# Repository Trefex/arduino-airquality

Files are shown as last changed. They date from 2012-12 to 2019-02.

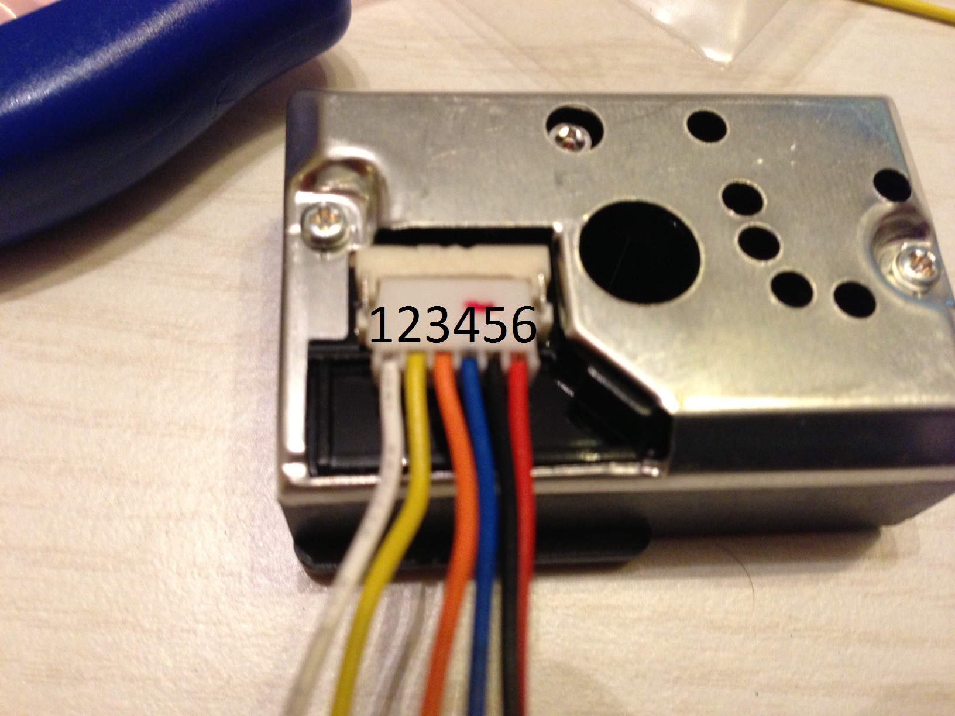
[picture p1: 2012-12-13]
Module_Dust-Sensor/assembly/_BlogImages/Arduino_Dust2.JPG

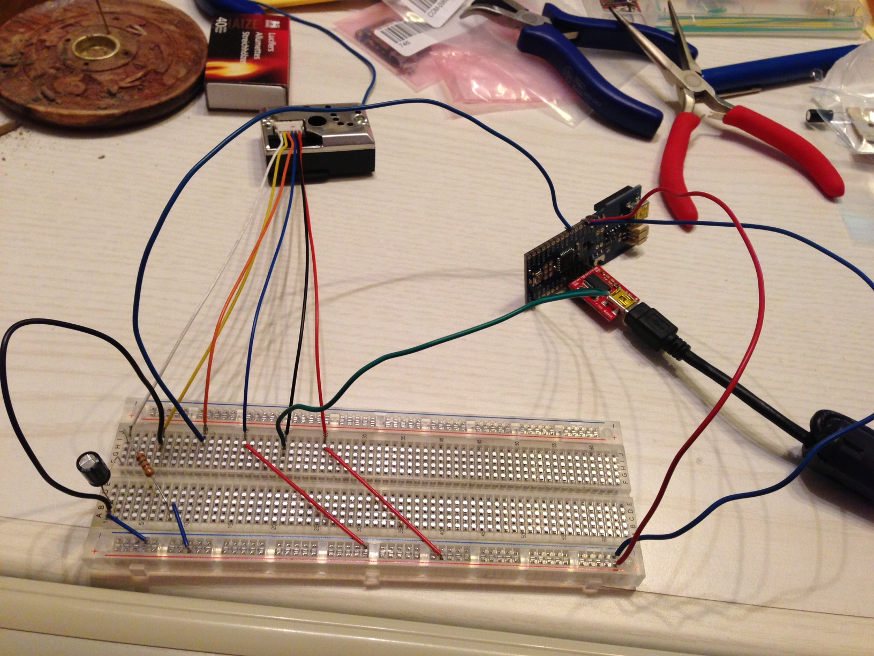
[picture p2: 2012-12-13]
Module_Dust-Sensor/assembly/_BlogImages/Arduino_Dust1.JPG

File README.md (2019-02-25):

arduino-airquality
==================
      
In this project, we are building a mobile Arduino Fio based platform to measure air quality.

We currently have multiple components working correctly with the Arduino Fio:

- [x] GPS sensor - Adafruit Ultimate GPS Breakout v3 and the OpenLog
- [x] Dust sensor - Sharp Optical Dust Sensor
- [x] Humidity and temperature sensor - SHT10 by sensiron/DFRobot
- [x] Carbon monoxide sensor - Parallax CO sensor
- [x] Barometric pressure - BMP085 Barometric Pressure/Temperature/Altitude Sensor

We are working on combining them all into a nice light package.

Still to do:
- [x] Create circuit board sketch and etch it
- [x] Solder everything on board
- [x] Build enclosure

Next version improvements:

1. Use smaller arduino board (Nano?) potentially one with GPS builtin.

2. Decide if we want a 5V board.

3. Use 7.4V LI-ion flat and rechargeable battery pack.

4. Use only one voltage regulator if we stay with 3.3V.

5. Move voltage splitter to monitor voltage to between battery and voltage regulator.

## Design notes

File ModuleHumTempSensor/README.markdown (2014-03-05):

SHT1x Temperature / Humidity Sensor Library for Arduino
=======================================================
Heavily modified by Cyrille Medard de Chardon from the original creator's version:

Copyright 2009 Jonathan Oxer jon@oxer.com.au / http://www.practicalarduino.com  
Copyright 2008 Maurice Ribble ribblem@yahoo.com / http://www.glacialwanderer.com

It now provides a simple interface to the SHT10 sensor made to function with the Arduino Fio (3.3V)

Installation
------------
Put this directory in your sketchbook and open the ino file.

Usage
-----
The library is instantiated as an object with methods provided to read
relative humidity and temperature. Include it in your sketch and then
create an object, specifying the pins to use for communication with the
sensor:

    #include "SHT1x.h"
    #define dataPin 10
    #define clockPin 11
    SHT1x sht10(dataPin, clockPin);

You can then call methods on that object within your program. In this
example we created an object called "sht10", but it could have been
called whatever you like.

### readTemperatureC() ###

Returns a float within the valid range of the sensor of -40 to +123.8C.
A value of -273 is returned in the event of a communication error with
the sensor.

Example:

    float tempC = sht10.readTemperatureC();

### retrieveTemperatureC() ###

Returns a float of the temperature in celcius that was measured during the humidity measurement. This prevents needing two calls to the temperature sensor. Call the humidty function readHumidity() then retrieveTemperatureC().

### readHumidity() ###

Returns a float within the valid range of the sensor of 0 to 100%.
A negative value is returned in the event of a communication error with
the sensor.

Example:

    float humidity = sht1x.readHumidity();

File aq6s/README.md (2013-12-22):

arduino-airquality - CO Sensor
==================

2013-Dec-22
	- You need to add the StandardCpp folder to your Arduino Library, or the Sketch will not compile

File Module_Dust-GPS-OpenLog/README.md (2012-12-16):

arduino-airquality - Combine Dust Sensor - GPS - OpenLog
==================

In this project, we are building a combination module of the Sharp Dust Sensor, the Adafruit Ultimate GPS Breakout v3 and the OpenLog using the Arduino Fio.

For a detailled documentation including a parts list, check out the following blog post
http://arduinodev.woofex.net/2012/12/16/sharp-dust-sensor-with-adafruit-gps-v3

# Assembly

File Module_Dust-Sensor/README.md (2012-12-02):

arduino-airquality - Dust Sensor
==================

In the Dust Sensor Module, we are building a standalone Dust Sensor using the Arduino Fio.

For a detailled documentation including a parts list, check out the following blog post
http://arduinodev.woofex.net/2012/12/01/standalone-sharp-dust-sensor/

# Assembly

Dust_SensorArduino

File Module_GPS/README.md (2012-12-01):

arduino-airquality - GPS
==================

In the GPS Module, we are building a standalone GPS device using the Arduino Fio.
This will be used as a module in the AirQuality project.

Stay tuned for updates.

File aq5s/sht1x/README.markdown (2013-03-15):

SHT1x Temperature / Humidity Sensor Library for Arduino
=======================================================
Heavily modified from the original creator's version:
Copyright 2009 Jonathan Oxer jon@oxer.com.au / http://www.practicalarduino.com  
Copyright 2008 Maurice Ribble ribblem@yahoo.com / http://www.glacialwanderer.com

Provides a simple interface to the SHT10 sensor. Made to function with the Arduino Fio (3.3V)

Installation
------------
Download the directory "SHT1x" and move it into the "libraries"
directory inside your sketchbook directory, then restart the Arduino
IDE. You will then see it listed under File->Examples->SHT1x.

Usage
-----
The library is instantiated as an object with methods provided to read
relative humidity and temperature. Include it in your sketch and then
create an object, specifying the pins to use for communication with the
sensor:

    #include <SHT1x.h>
    #define dataPin 10
    #define clockPin 11
    SHT1x sht10(dataPin, clockPin);

You can then call methods on that object within your program. In this
example we created an object called "sht10", but it could have been
called whatever you like. A complete example program is included with
the library and can be accessed from the File->Examples->SHT1x menu.

### readTemperatureC() ###

Returns a float within the valid range of the sensor of -40 to +123.8C.
A value of -273 is returned in the event of a communication error with
the sensor.

Example:

    float tempC = sht10.readTemperatureC();

### retrieveTemperatureC() ###

Returns a float of the temperature in celcius that was measured during the humidity measurement. This prevents needing two calls to the temperature sensor. Call the humidyt function readHumidity() then retrieveTemperatureC().

### readHumidity() ###

Returns a float within the valid range of the sensor of 0 to 100%.
A negative value is returned in the event of a communication error with
the sensor.

Example:

    float humidity = sht1x.readHumidity();

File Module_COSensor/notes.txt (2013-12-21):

Note regarding Gas Sensor Module (GSM)
- only interested in TP1 which varies from 0V - 5V
- not interested in other TP (TP2/4 GRND, TP3 Alarm trip level)
- don't need to calibrate trip level screw on left, other than set it very high so it actually is a coherent visual warning..
- adding a 1k resistor between TP1 and Fio
- soldered wire to TP1

CO sensor:
When heating should pull about 165 mA, 60mA when 'off'
Needs a 5V signal to heat switch (HSW) to turn it on
Needs a 1.4V signal to HSW to let the sensor 'cool'

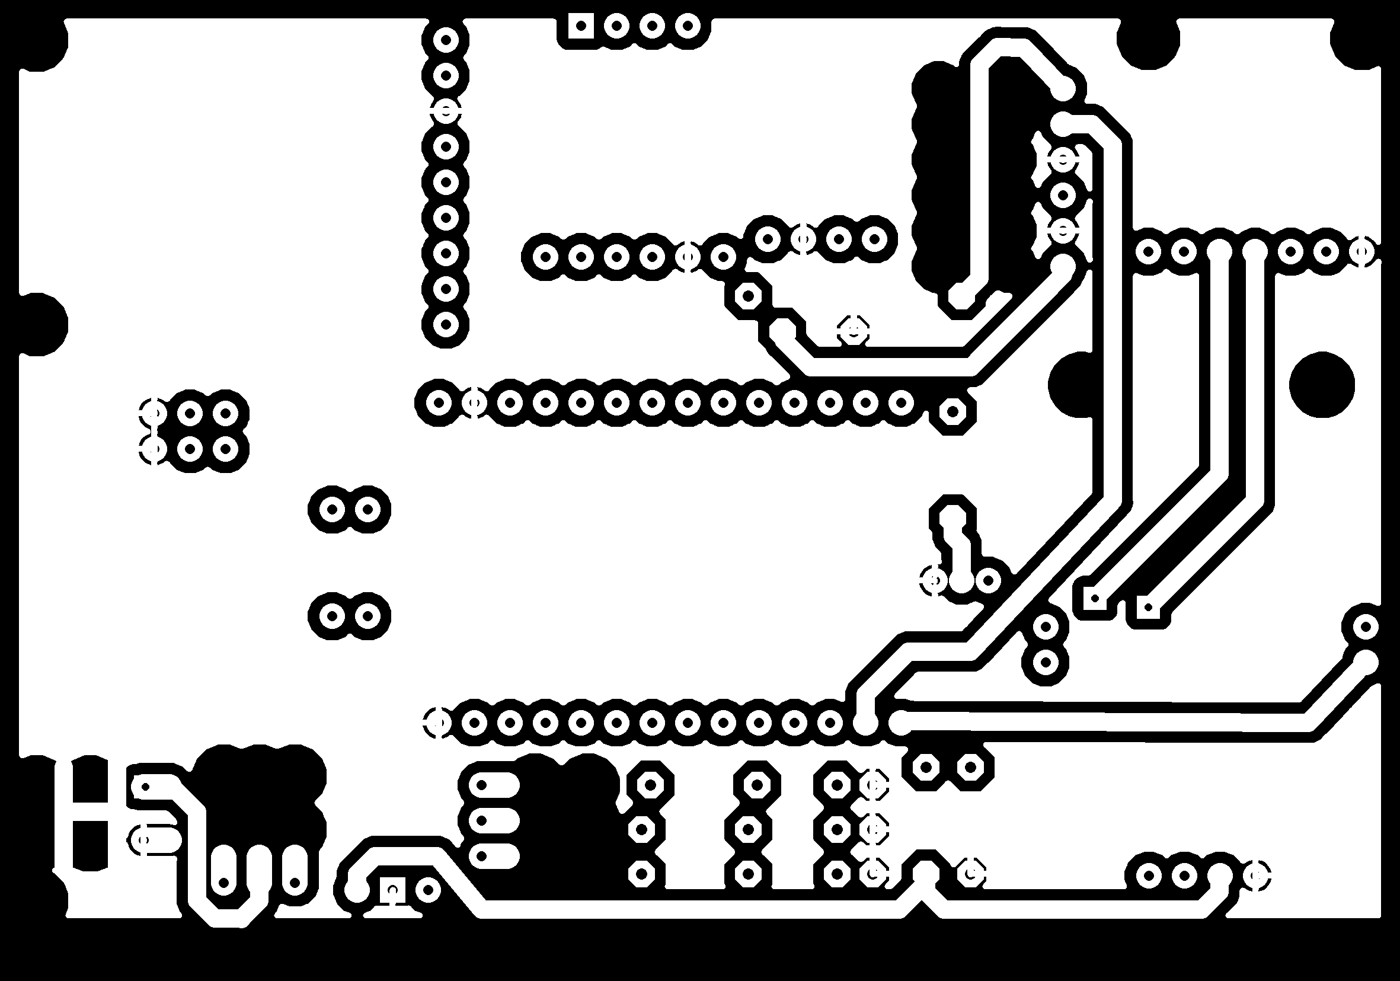
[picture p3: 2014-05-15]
schematics/Eagle/aq6s/pcb_design/top.png

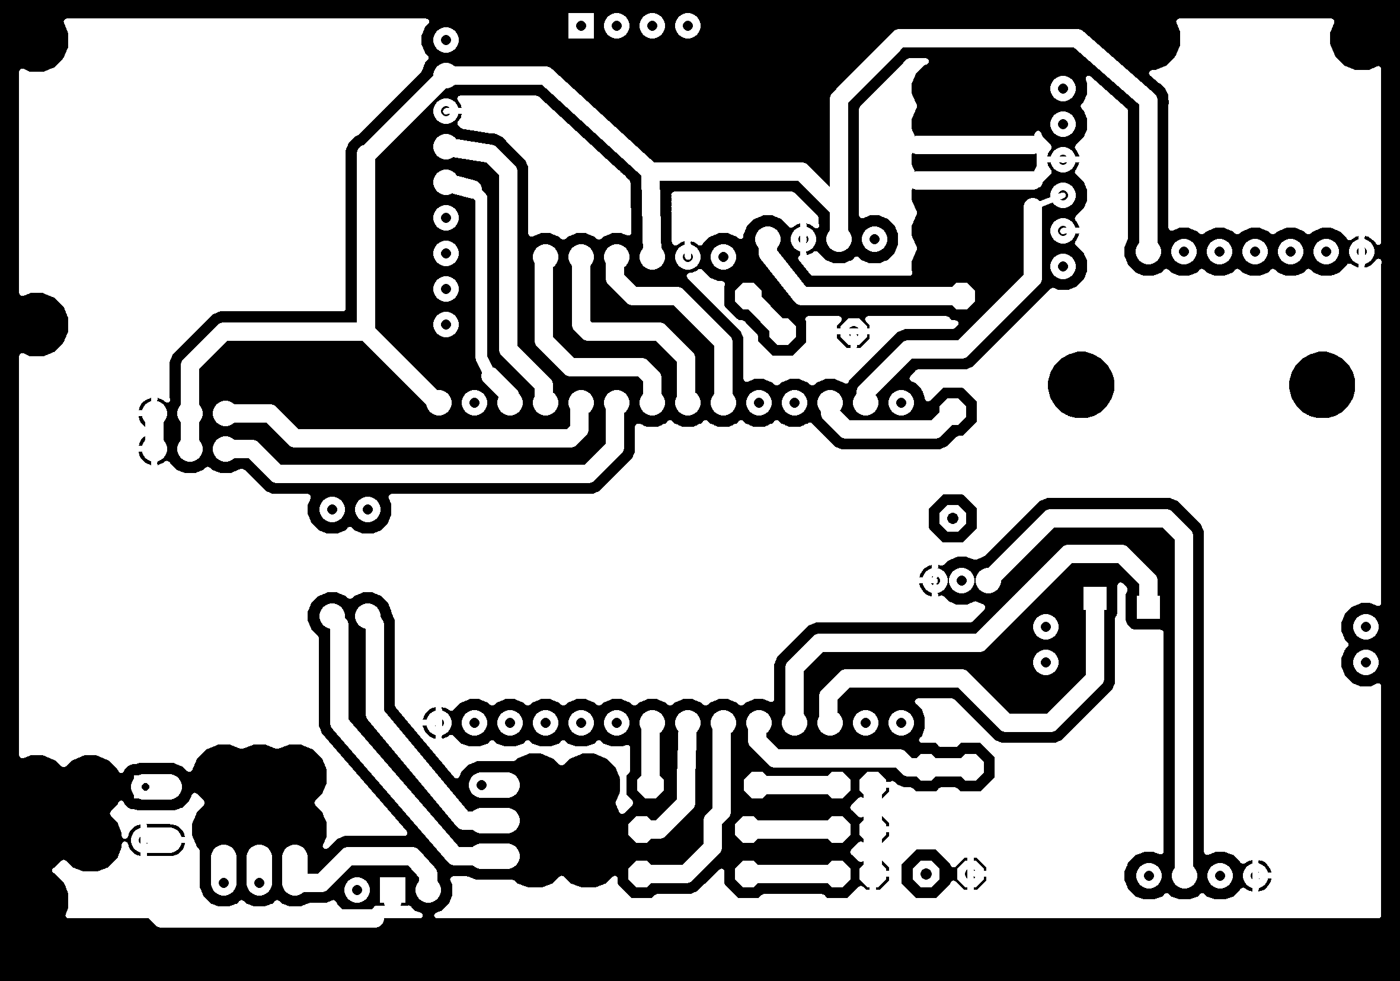
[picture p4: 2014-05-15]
schematics/Eagle/aq6s/pcb_design/bottom.png

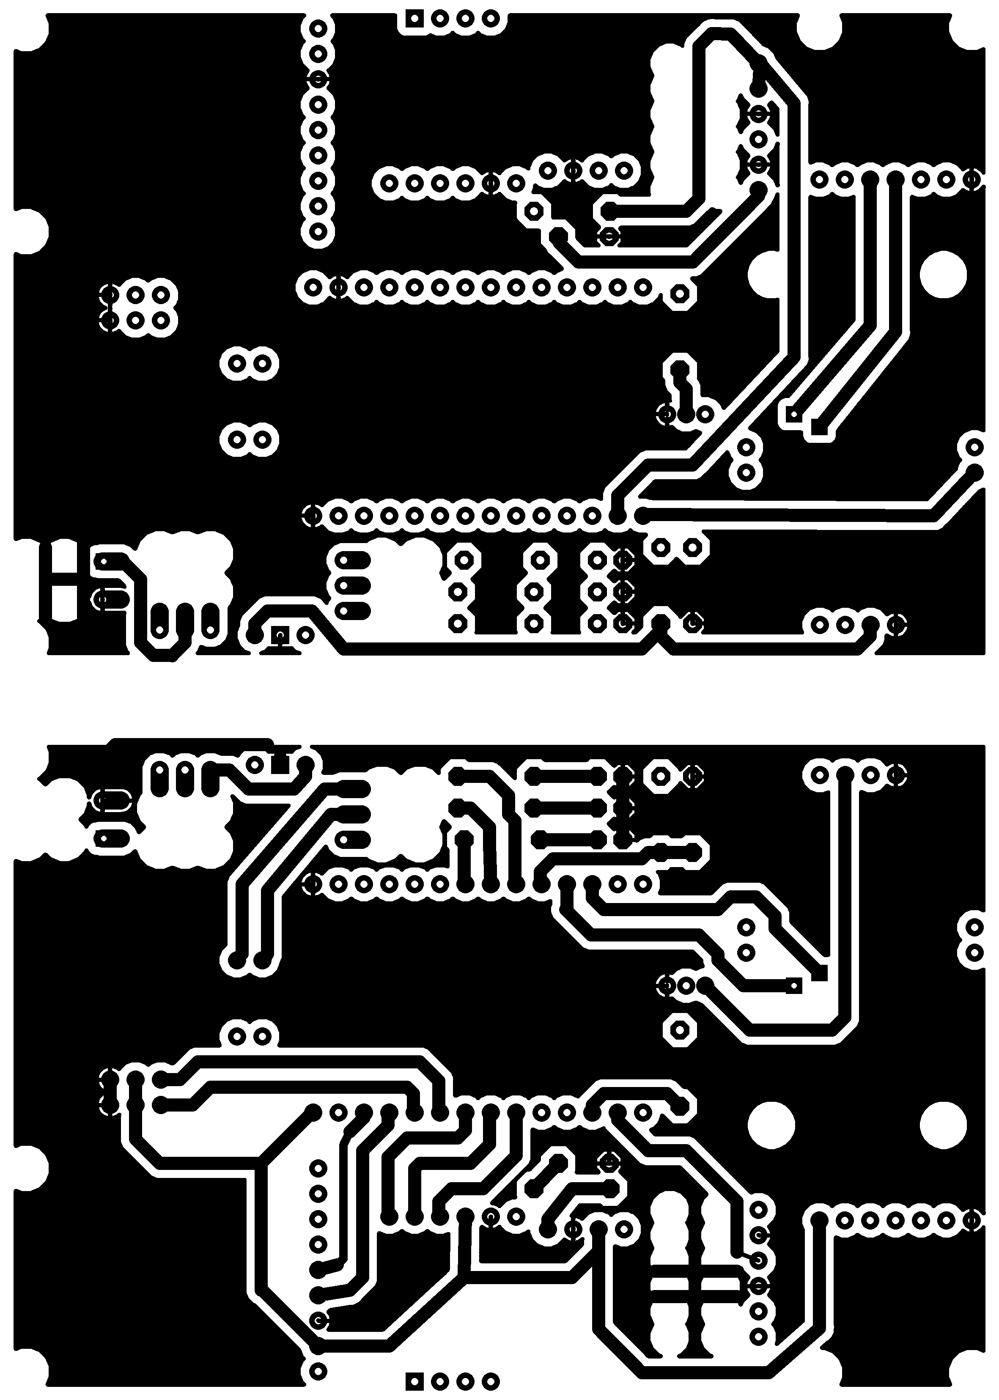
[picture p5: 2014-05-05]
schematics/Eagle/aq6s/pcb_design/both.png

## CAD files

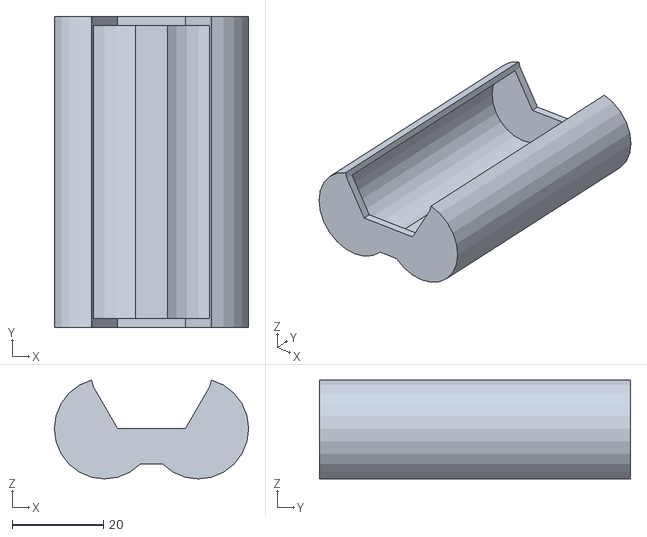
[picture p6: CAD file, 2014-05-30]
battery_holder/battery_holder.stl
42.5 x 68.0 x 21.6

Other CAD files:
battery_holder/battery_holder.skp
battery_holder/battery_holder_stretch.skp
battery_holder/battery_holder_stretch~.skp
battery_holder/battery_holder~.skp

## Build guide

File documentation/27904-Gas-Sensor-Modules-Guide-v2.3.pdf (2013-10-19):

Web Site: www.parallax.com Forums: forums.parallax.com Sales: sales@parallax.com
Technical: support@parallax.com

Office: (916) 624-8333
Fax: (916) 624-8003
Sales: (888) 512-1024
Tech Support: (888) 997-8267

Copyright © Parallax Inc. Gas Sensor Modules (#27930, #27931, #27932, #27904) v2.3 11/27/2012 Page 1 of 5

# Parallax Gas Sensor Modules

CH4 (Methane) Gas Sensor Module (#27930)
CO (Carbon Monoxide) Gas Sensor Module (#27931)
LPG (Propane) Gas Sensor Module (#27932)
C2H5OH (Alcohol) Gas Sensor Module (#27904)

These Gas Sensor Modules are designed to allow a microcontroller to determine when a preset gas level has been reached or exceeded. The type of gas detected depends on which module you are using. 27930 detects Methane (CH4), 27931 detects Carbon Monoxide (CO), 27932 detects Propane (LPG) and 27904 detects Alcohol (C2H5OH). Interfacing with these sensors is done through a 4-pin SIP header and requires two I/O pins from the host microcontroller. The sensor modules are intended to provide a means of comparing gas sources and being able to set an alarm limit when the source becomes excessive.

Parallax does not provide gas calibration data on these modules and such data as well as the alarm settings are the responsibility of the user to define. For information on calibration please see page 3.

### Features

- Easy SIP header interface
- Compatible with most microcontrollers
- Low-power standby mode

### Key Specifications

- Power requirements: 5 VDC @ ~165 mA (heater on) / ~60 mA (heater off)
- Interface: 1 TTL compatible input (HSW); 1 TTL compatible output (ALR)
- Operating temperature:
14 to 122 °F (-10 to +50°C)
- Dimensions: 1.50 x 1.0 x 1.0 in
(38.1 x 25.4 x 25.4 mm)

### Application Ideas

- Gas level over-limit alarm
- Stand-alone/background sensing device
- Environmental monitoring equipment

### Packing List

- Gas Sensor
- Gas Sensor PCB Assembly

### Other Items Required

- Tiny flat-head screwdriver
- A source of gas for calibration

### Product Change Notice

This documentation is written for the Gas Sensor Modules listed at the top of this documentation that include a PCB labeled “Gas Sensor Board Rev A (#27983).” If you have a product where the PCB is labeled “Gas Sensor Module” with the gas type and one of the following part numbers on the PCB (27930, 27931, 27932, 27904), please see the Product Change Notice Details on page 5.

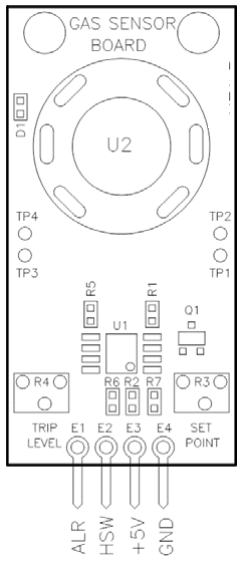
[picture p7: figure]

Copyright © Parallax Inc. Gas Sensor Modules (#27930, #27931, #27932, #27904)v2.3 11/27/2012 Page 2 of 5

### Precautions

Be aware that the gasses detected by these gas sensors can be deadly in high concentrations. Automotive exhaust and charcoal cooking grill exhausts emit carbon monoxide (CO). Propane Gas (LPG) can leak from propane grills and furnaces and Methane (CH4) can be found in animal farming areas. Always be careful to perform gas tests in well-ventilated areas.

THESE GAS SENSOR MODULES ARE NOT DESIGNED FOR OR APPROVED FOR ANY APPLICATION INVOLVING HEALTH OR HUMAN SAFETY. THESE GAS SENSOR MODULES ARE FOR EXPERIMENTAL PURPOSES ONLY. PARALLAX, INC. ABSOLVES ITSELF OF ALL LIABILITY AND RESPONSIBILITY ASSOCIATED WITH THE CUSTOMER'S USE OF THESE GAS SENSOR MODULES AND IS NOT RESPONSIBLE FOR ANY BODILY INJURY, DEATH OR PROPERTY DAMAGE AS A RESULT OF USING THESE GAS SENSOR MODULES.

### Connecting and Testing

The gas sensor canister plugs into the socket on the front of the module. The gas sensors are essentially resistive devices and are not polarized, so there is no need to be concerned about plugging it in “backwards.” It will work in either orientation.

The 4-pin SIP header on the Gas Sensor Module makes it easy to connect to a breadboard or SIP socket. The four connections are defined in the table below. Connection to a 5V microcontroller, such as the BASIC Stamp® module, would be pretty straight forward and require two I/O pins; one input for detecting the alarm signal and the other an output for controlling the internal heater.

For a 3.3 V microcontroller such as the PropellerTM chip, a 3.9 kΩ–10 kΩ resistor would be required from the ALR output to the Propeller chip input pin.

### Pin Definitions and Ratings – Gas Sensor Board

Pin | Name | Function | Level
E1 | ALR | Alarm output to host microcontroller | 0V / 5V
E2 | HSW | Heat switch input from microcontroller, active high | 0V / High*
E3 | +5V | +5 VDC power | 5V
E4 | GND | Ground, connects to common ground | 0V
TP1 | Test Point 1+ | Buffered output of sensors (voltage divider) | 0V – 5V
TP2 | Test Point 2- | Ground, connects to common ground | 0V
TP3 | Test Point 3+ | Trip Level voltage set by potentiometer (R4) | 0V – 5V
TP4 | Test Point 4- | Ground, connects to common ground | 0V
* The HSW can be activated from 3-5 VDC and has an internal 150 kΩ pull-down resistor.
NOTE: Sensor may rattle if shaken – this is normal.

Copyright © Parallax Inc. Gas Sensor Modules (#27930, #27931, #27932, #27904)v2.3 11/27/2012 Page 3 of 5

### Theory of Operation

These gas sensor modules use gas sensors from Hanwei Electronics. When their internal heating elements are activated, they respond to their specific gas by reducing their resistance in proportion to the amount of that gas present in the air exposed to the internal element. On the gas sensor modules this is part of a voltage divider formed by the internal element of each gas sensor and potentiometer R3 (Set Point). The output of this voltage divider is fed into the non-inverting inputs of the two op-amps on the LT1013 dual op-amp IC. Op-amp A is configured as a buffer with unity gain and is used to provide a non-loaded test point for the signal voltage at TP1 (+) and TP2 (-). The signal voltage is also being fed into op-amp B which is configured as a comparator that gets its reference voltage at the inverting input from potentiometer R4 (Trip Level) and is also available at TP3 (+) and TP4 (-).

The output of op-amp B goes out to the ALR pin through a 1 kΩ resistor providing a TTL-compatible signal to a microcontroller. This output also connects to a red LED on the gas sensor modules. The zero gas span adjustment is set via potentiometer R3. As mentioned above R3 allows you to change the span/range of the voltage divider formed by the gas sensor and R3 which is the bottom leg of the divider, electrically speaking. Adjusting R3 to lower values will make the gas sensor less sensitive but more stable. Avoid setting R3 below 200 ohms as at this point you will be close to shorting the output to ground. Setting R3 to higher values will make the gas sensor more responsive, but without a minimum load it will become unstable after a certain point. The trip level adjustment is set via potentiometer R4. This is just a simple voltage divider that lets you set the voltage from 0V to 5V. This voltage is compared to the voltage coming from the gas sensor/R3 divider. When the voltage from the gas sensor is higher than the voltage set by potentiometer R4 the red LED will light and the ALR output will be high (5 V). The section below describes how to configure these gas sensor modules to detect gas with minimal calibration.

One more important item to consider when setting R3 during calibration is the load resistance recommended in the datasheet for each gas sensor. Potentiometer R3 should be set as close as possible to the load resistance recommended for the gas sensor you’re using.

### Calibration

The procedure for setting these potentiometers is explained below. Please note that turning the potentiometer clockwise decreases voltage, while turning the potentiometer counter-clockwise increases it. This can be compared to a water valve.

- For the CO sensor, please read the CO Sensor Specifics on page 4 before attempting calibration.
- Place the Gas Sensor Module in a clean air environment and supply power to the module. The heater should be active during this time. Allow at least 10 minutes before making adjustments.
- Adjust potentiometer R4 until the voltage across TP3 (+) and TP4 (-) reads ~ 0.80 V.
- Adjust potentiometer R3 until the voltage across TP1 (+) and TP2 (-) reads ~ 0.80 V.
- At this point adjusting R3 up/down should make the LED toggle on/off. Adjust R3 so the LED just goes off.
- Apply your gas source to the gas sensor. The LED should light up.
- Remove the gas source and allow the sensor to settle. The LED should go back out.
- If the LED does not go out within 60 seconds, adjust R3 until the LED goes out and repeat the two previous steps.

The gas sensor module’s ALR pin should only be checked when the heater is on and the readings have stabilized. Note that temperature and humidity are factors that could affect the sensor, making calibration difficult. If this should happen try adjusting the voltages used in the calibration up or down as necessary to find a more stable range.

Copyright © Parallax Inc. Gas Sensor Modules (#27930, #27931, #27932, #27904)v2.3 11/27/2012 Page 4 of 5

### CO Sensor Specifics

The CO gas sensor must cycle through alternating voltages on its heater when active. This is unlike the CH4, LPG, and C2H5OH gas sensors where the heater is on or off. To sense CO gas using the CO gas sensor the heater must be driven at 5 V (full power) for the purge phase and 1.4 V (low power) for the sense phase. The full-power (purge) phase runs for 60 seconds and the low-power (sense) phase runs for 90 seconds. These phases cycle continuously as long as the sensor is active. The ALR output is checked during the sense phase only. Checking it during the purge phase or when the heater is not active could result in false positives.

In order to power the CO gas sensor from 5V and still obtain 1.4 V for the sense phase it is necessary to pulse-width modulate (PWM) the HSW pin. Example source code is provided for the BASIC Stamp 2 module (see your gas sensor’s product page; search by stock code at http://www.parallax.com) and Propeller chip (see the Propeller Object Exchange, http://obex.parallax.com).

### Sources of Gas for Calibration / Testing

The use of a standard butane hair curler is an easy, safe source to use for a very low carbon monoxide (CO) gas concentration (less than 500 ppm) and can be used during calibration and testing of the CO Gas Sensor Module.

An unlit propane torch can be used as a source for calibration and testing of the LPG Gas Sensor Module. These are readily available from any hardware store and most department stores. Be careful not to leave the valve open very long. Simply cracking the valve just a little can trigger the gas sensor.

We have not found an easy reliable source of methane for calibration and testing of the CH4 Gas Sensor Module, however the CH4 gas sensor is responsive to propane as well so that could be used for testing.

Breathing gently through a small plastic tube (a drinking straw will work) can be used for calibrating the C2H5OH Gas Sensor Module. The tube will help get the gas to the sensor and should condense most of the water vapor in your breath that may interfere with the sensor. Breathe out very, very slowly! Air movement across the sensor can cool the heater, causing erroneous readings.

### Resources and Downloads

You may download the module schematic as well as the manufacturer datasheet for the sensor from each gas sensor module’s product page. Go to http://www.parallax.com, and search by the specific product number.

For gas calibration information you can also visit the following PDF on this website: http://www.gotgas.com/pdf/GasSnsrCalibratn.pdf

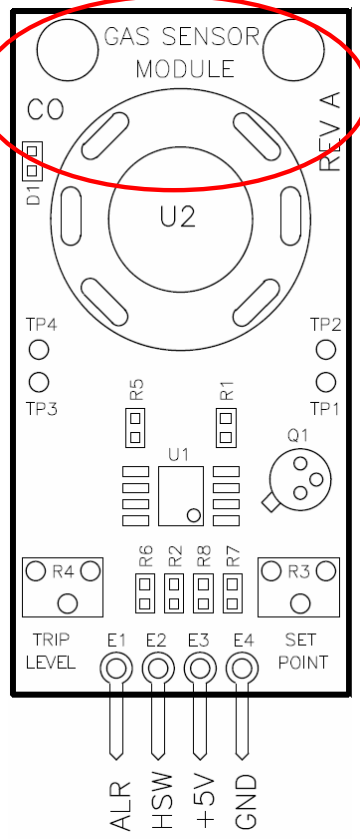
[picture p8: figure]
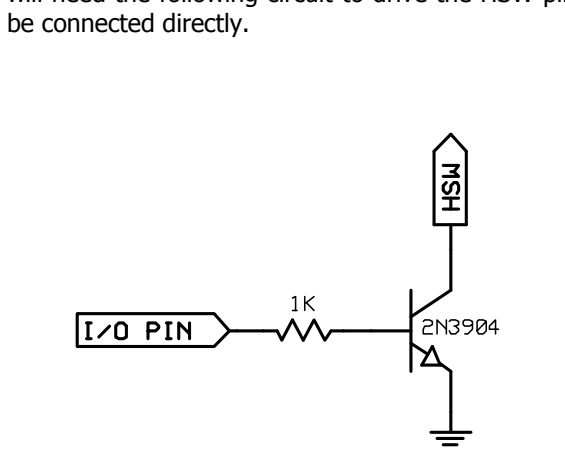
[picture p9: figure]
be connected directly.

Copyright © Parallax Inc. Gas Sensor Modules (#27930, #27931, #27932, #27904)v2.3 11/27/2012 Page 5 of 5

### Product Change Notice Details

This section applies to covers product numbers 27930, 27931, 27932 and 27904 where the PCB is labeled as “Gas Sensor Module” with the type of gas indicated below the left mounting hole (see drawing, right).

The HSW input is active-low and is pulled to 5 V via an internal 10 kΩ resistor.

Code examples (especially those using the CO sensor) will require changes to drive the line low at the desired duty cycle during on times and release the pin during off times. You can release an I/O pin by making it an input.

If you have a 3.3 V microcontroller such as the Propeller chip you will need the following circuit to drive the HSW pin as it should not

### Pin Definitions and Ratings – Gas Sensor Modules

Pin | Name | Function | Level
E1 | ALR | Alarm output to host microcontroller | 0V / 5V
E2 | HSW | Heat switch input from microcontroller, active low | 0V / Floating*
E3 | +5V | +5 VDC power | 5V
E4 | GND | Ground, connects to common ground | 0V
TP1 | Test Point 1+ | Buffered output of sensors (voltage divider) | 0V – 5V
TP2 | Test Point 2- | Ground, connects to common ground | 0V
TP3 | Test Point 3+ | Trip Level voltage set by potentiometer (R4) | 0V – 5V
TP4 | Test Point 4- | Ground, connects to common ground | 0V
* The HSW line is internally pulled up to 5 V via a 10 kΩ resistor.
NOTE: Sensor may rattle if shaken – this is normal.

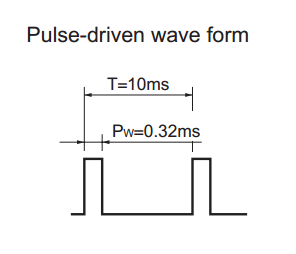
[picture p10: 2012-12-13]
Module_Dust-Sensor/assembly/_BlogImages/Sharp_PulseWidth.PNG

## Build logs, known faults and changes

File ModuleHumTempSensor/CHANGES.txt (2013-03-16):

2013-03-16
 * Renamed and moved files, changed #include path, now works out of the box with arduino
2013-02-22
 * Completely changed the library to handle Arduion Fio's 3.3V.
 * Minor fixes/cleaning
 * Removed fahrenheit functions for temperature
 * Removed direct temperature requests, can only be requested after a humidity request (this prevents too many sequential temperature requests which will heat the sensor... (humidity request do a temperature request, we hold this for later retrieval)

2011-09-20
 * Conditionally include Arduino.h for compatibility with Arduino 1.0

2010-07-23
 * Added SHT7x to list of supported sensors.
 * Fixed temperature offset in humidity calculation.

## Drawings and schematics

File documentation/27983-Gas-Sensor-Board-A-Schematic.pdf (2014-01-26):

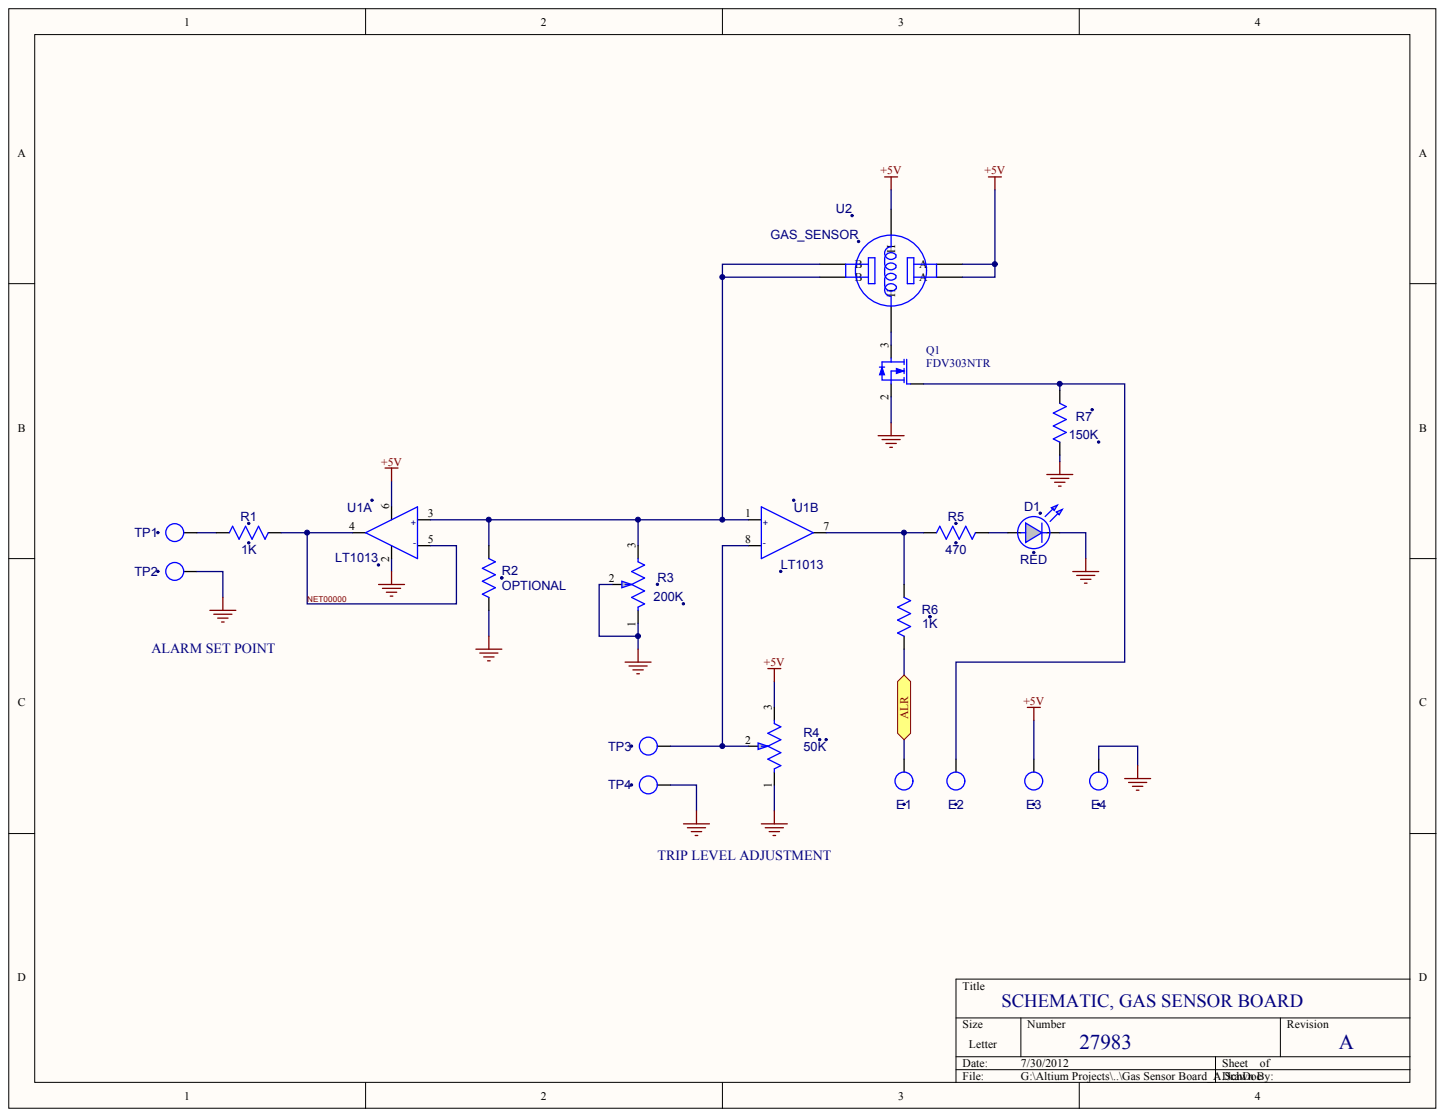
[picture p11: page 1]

SCHEMATIC, GAS SENSOR BOARD

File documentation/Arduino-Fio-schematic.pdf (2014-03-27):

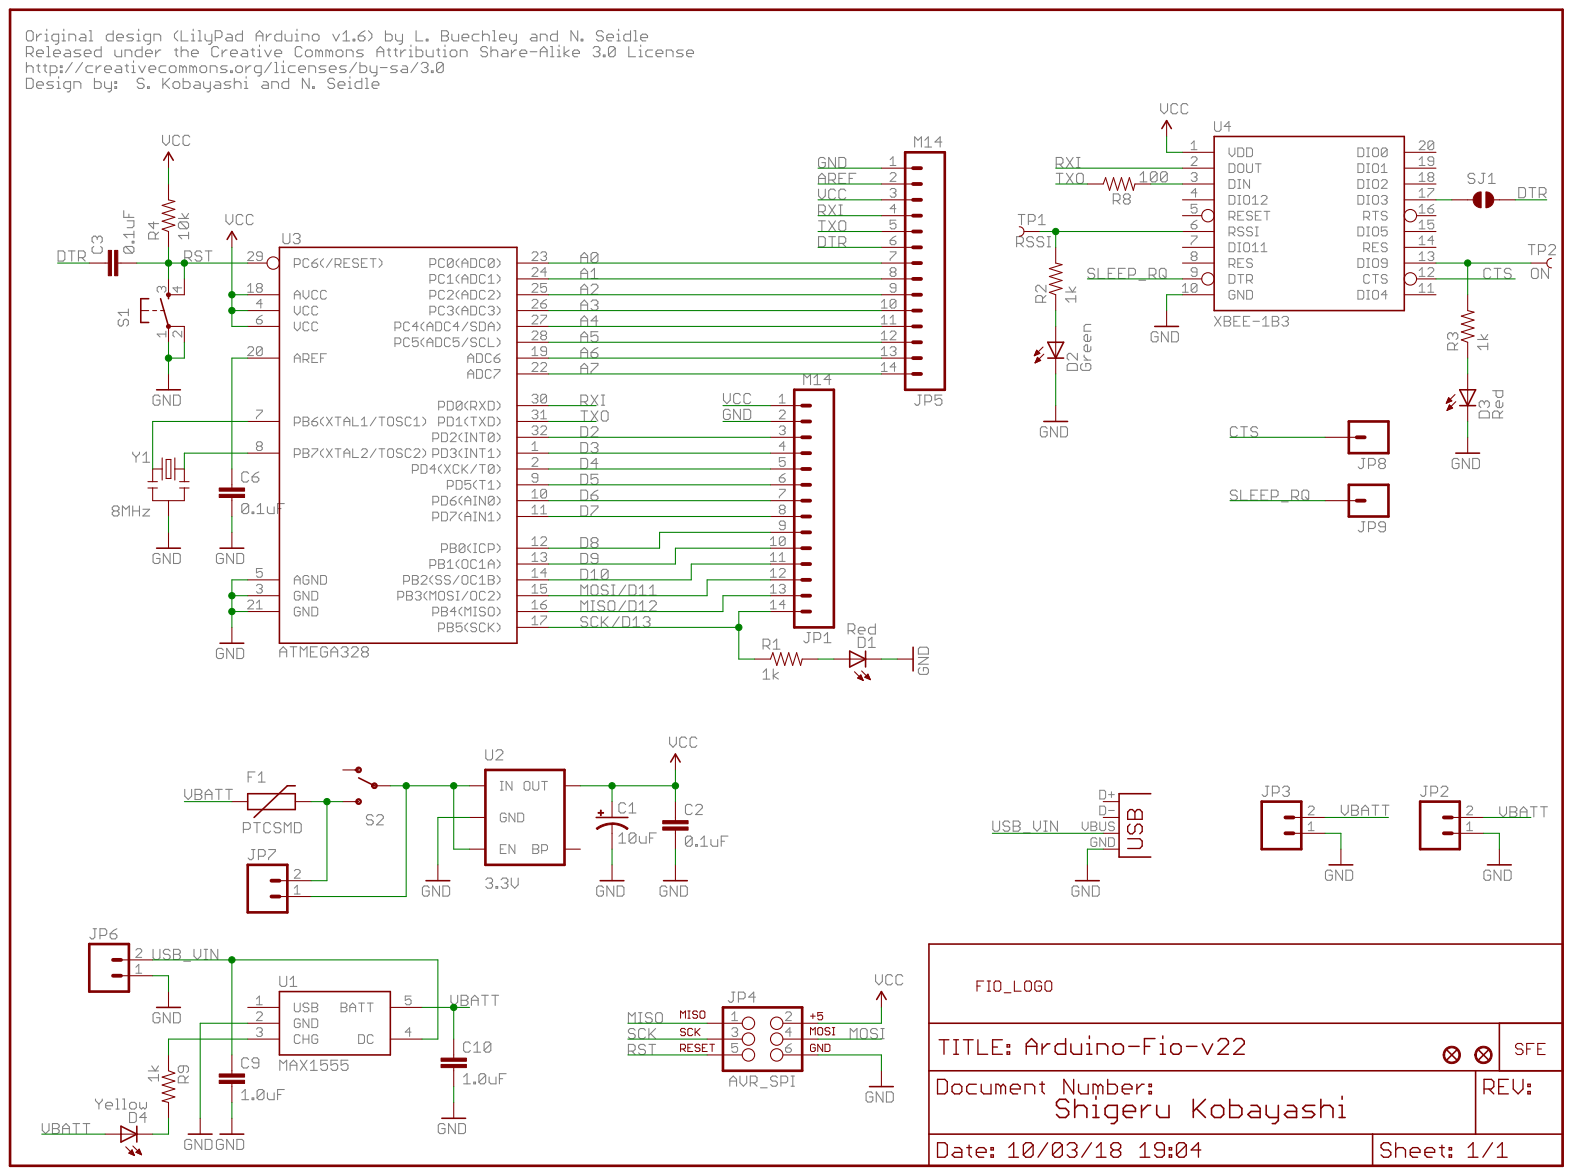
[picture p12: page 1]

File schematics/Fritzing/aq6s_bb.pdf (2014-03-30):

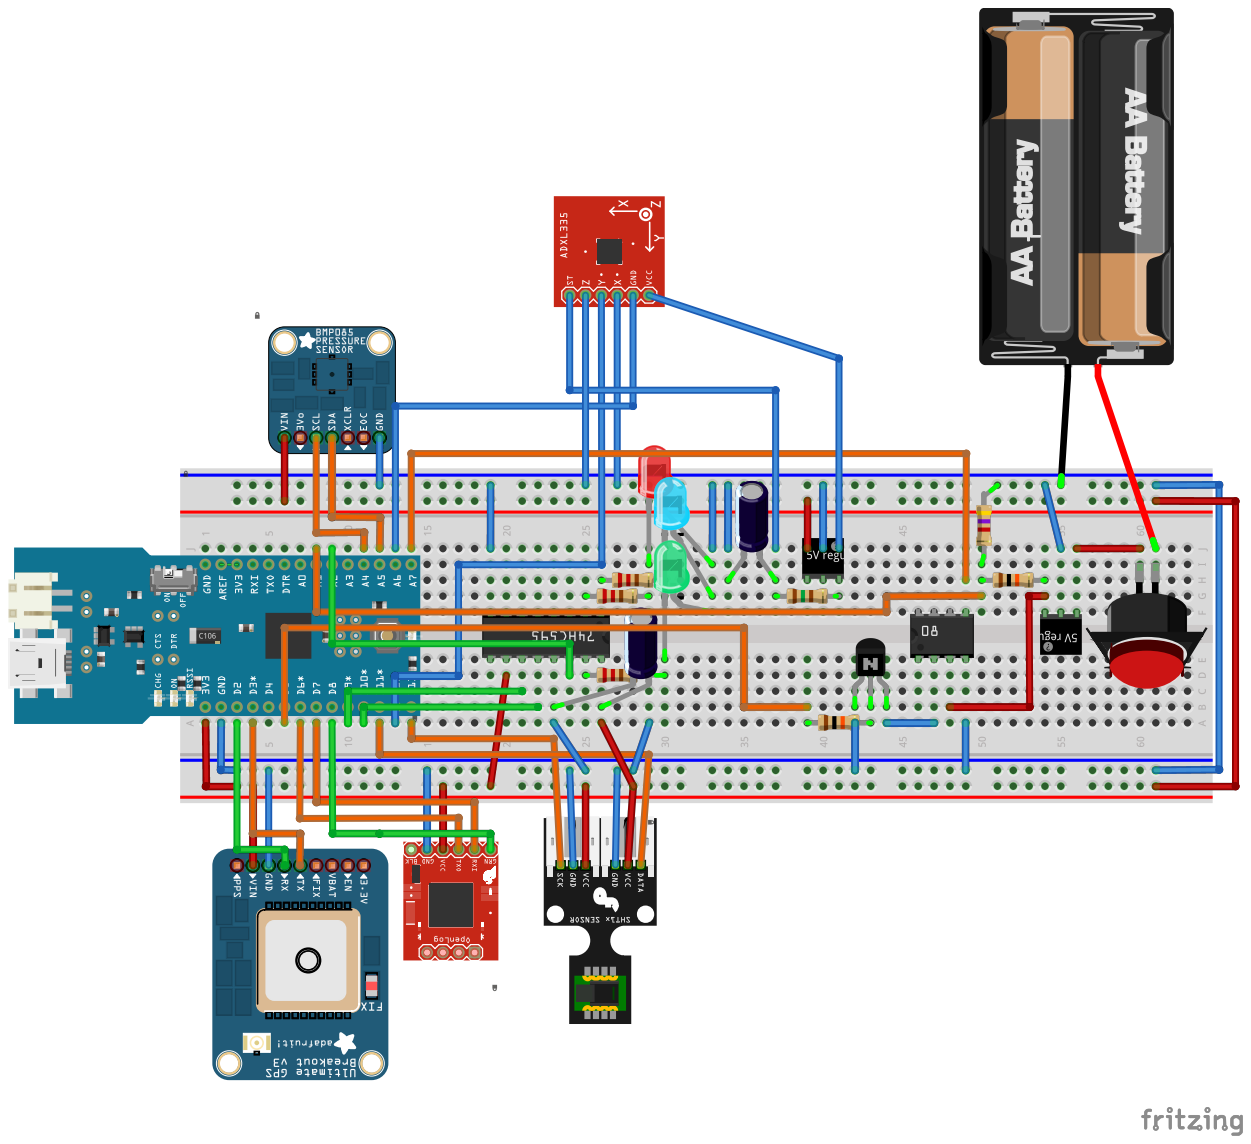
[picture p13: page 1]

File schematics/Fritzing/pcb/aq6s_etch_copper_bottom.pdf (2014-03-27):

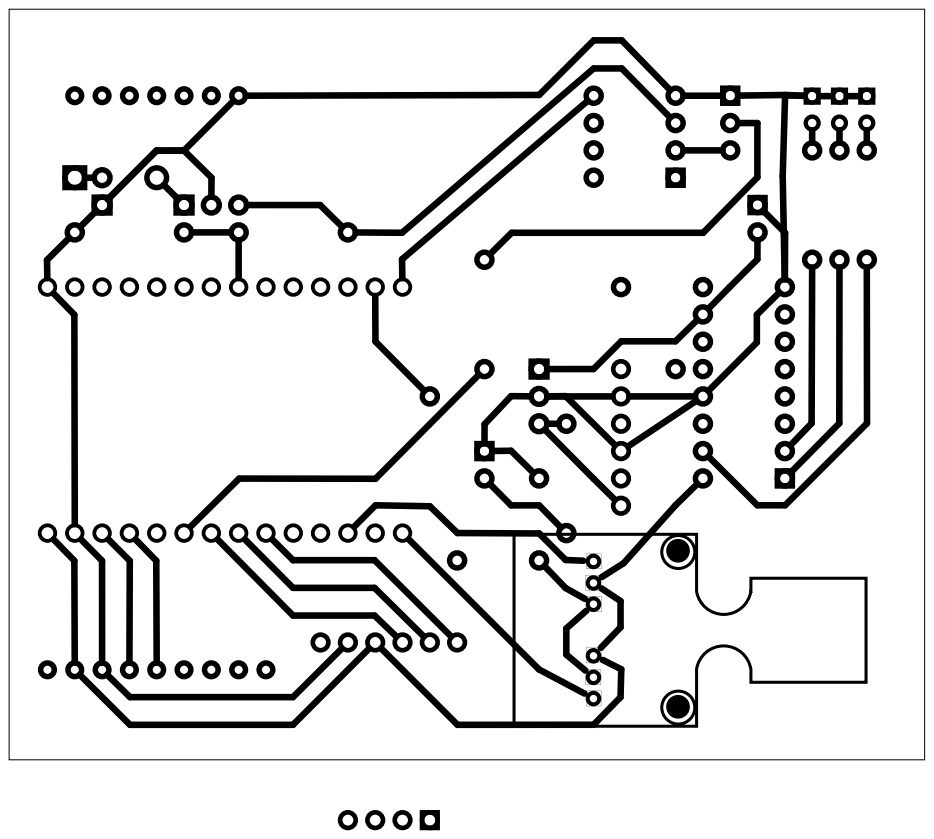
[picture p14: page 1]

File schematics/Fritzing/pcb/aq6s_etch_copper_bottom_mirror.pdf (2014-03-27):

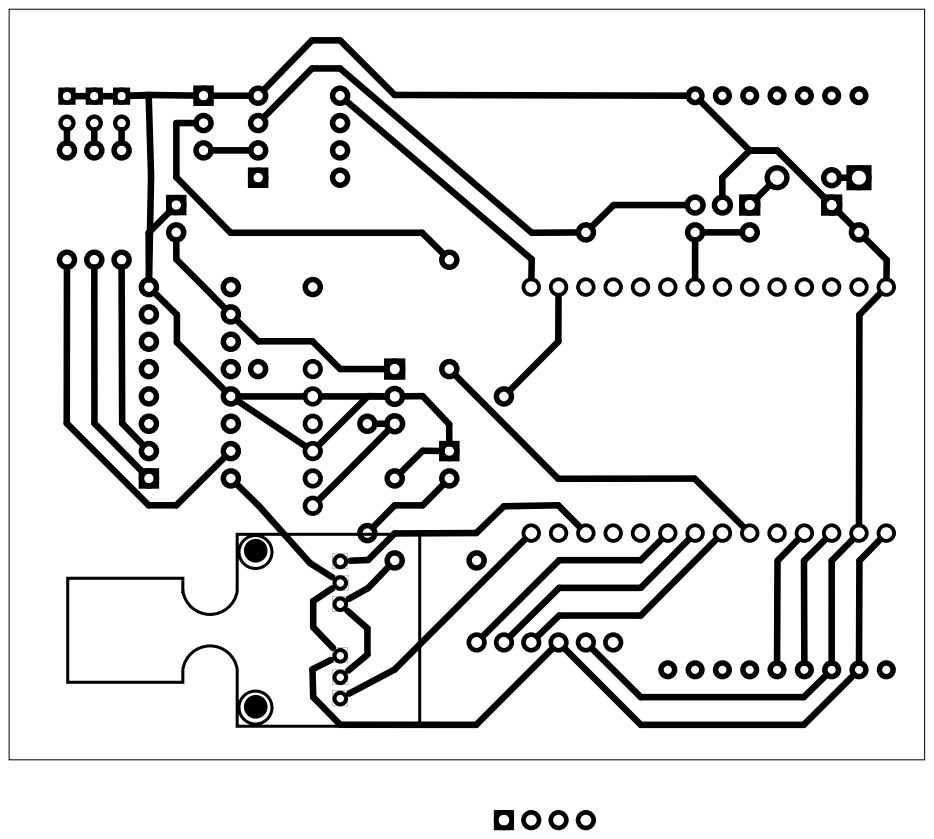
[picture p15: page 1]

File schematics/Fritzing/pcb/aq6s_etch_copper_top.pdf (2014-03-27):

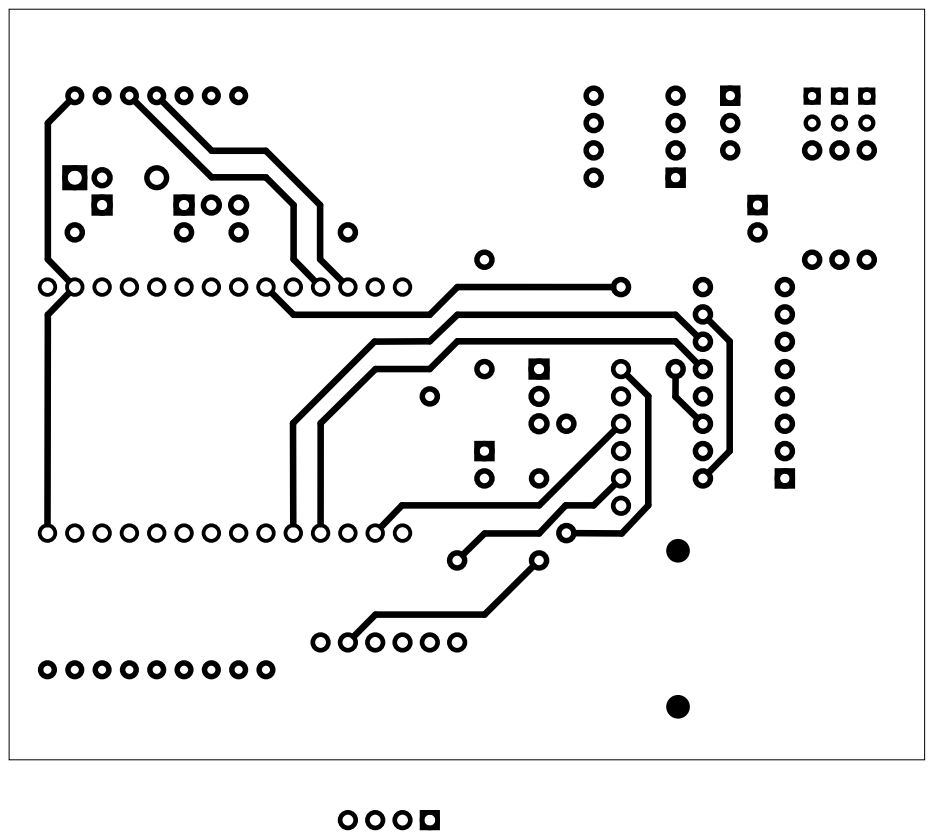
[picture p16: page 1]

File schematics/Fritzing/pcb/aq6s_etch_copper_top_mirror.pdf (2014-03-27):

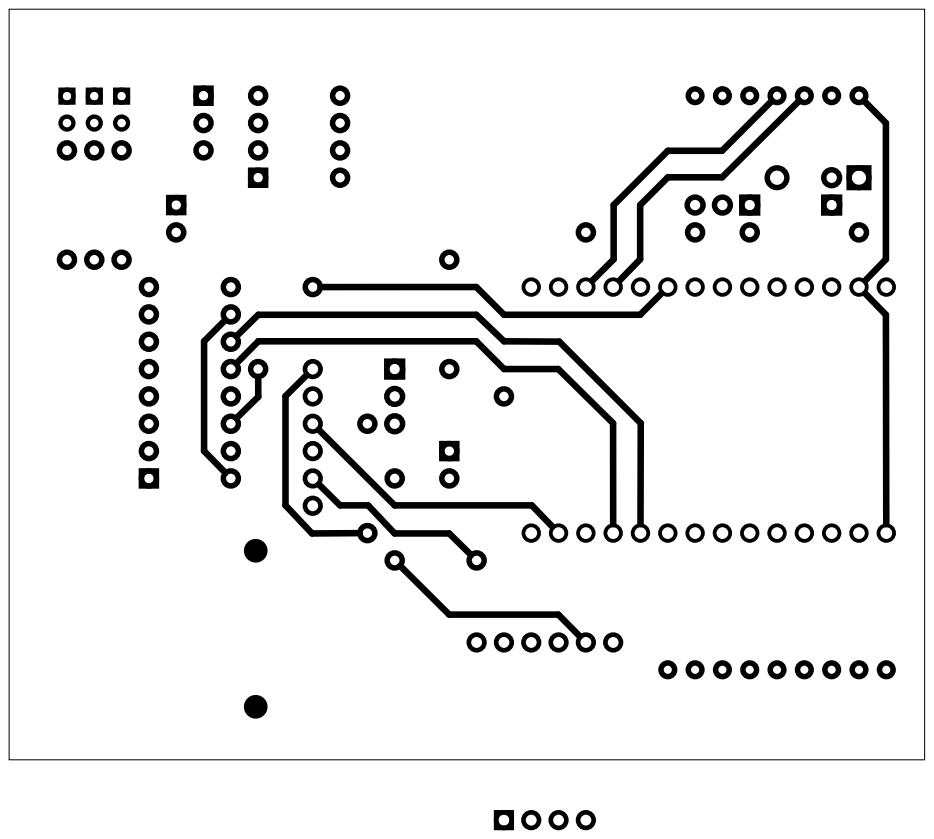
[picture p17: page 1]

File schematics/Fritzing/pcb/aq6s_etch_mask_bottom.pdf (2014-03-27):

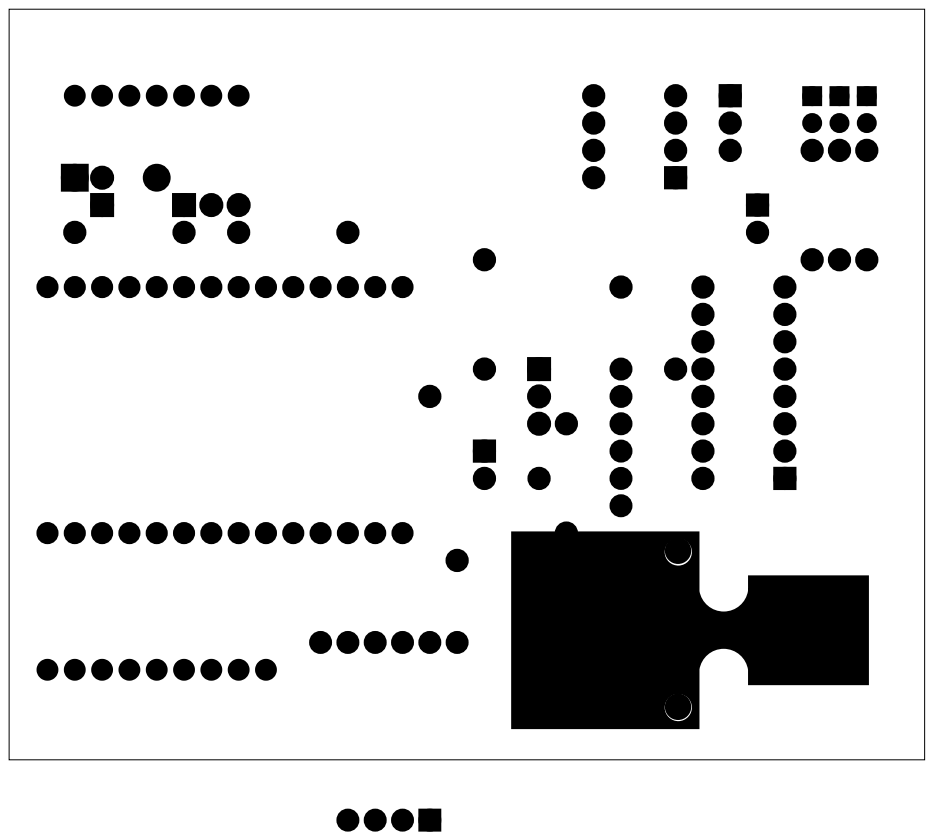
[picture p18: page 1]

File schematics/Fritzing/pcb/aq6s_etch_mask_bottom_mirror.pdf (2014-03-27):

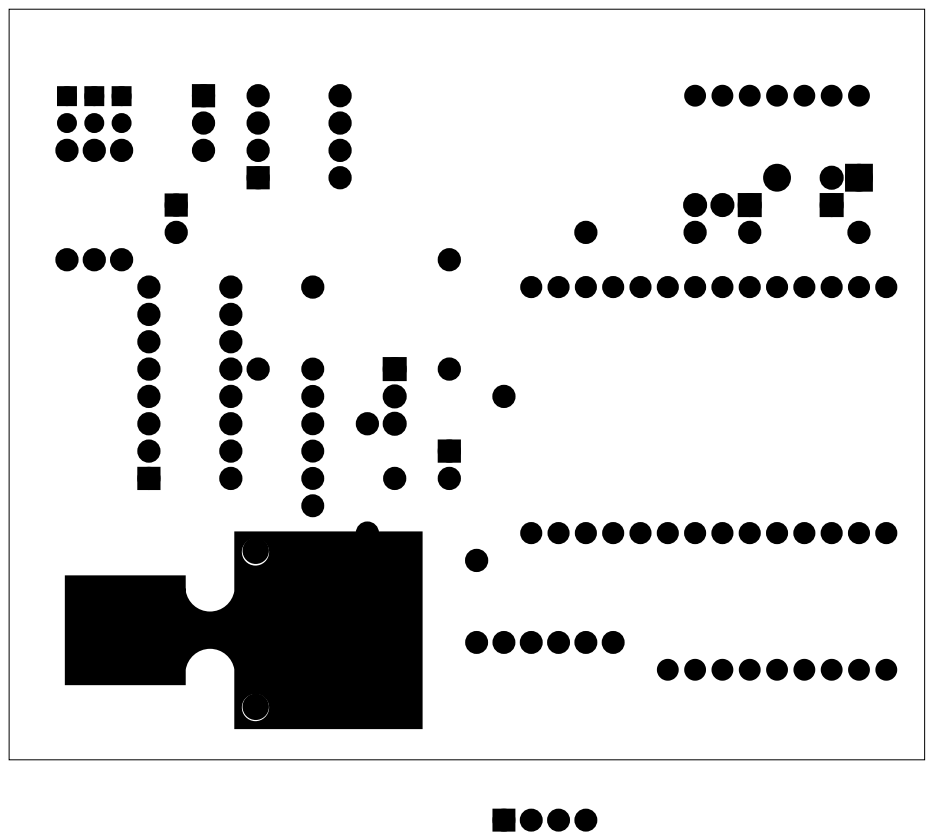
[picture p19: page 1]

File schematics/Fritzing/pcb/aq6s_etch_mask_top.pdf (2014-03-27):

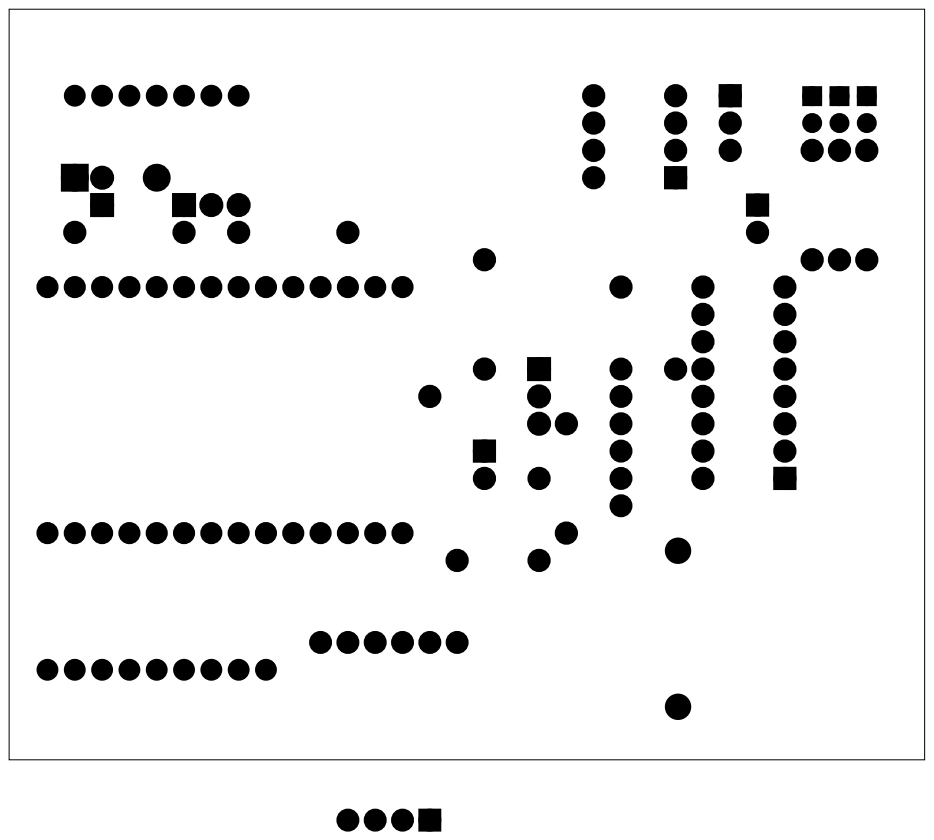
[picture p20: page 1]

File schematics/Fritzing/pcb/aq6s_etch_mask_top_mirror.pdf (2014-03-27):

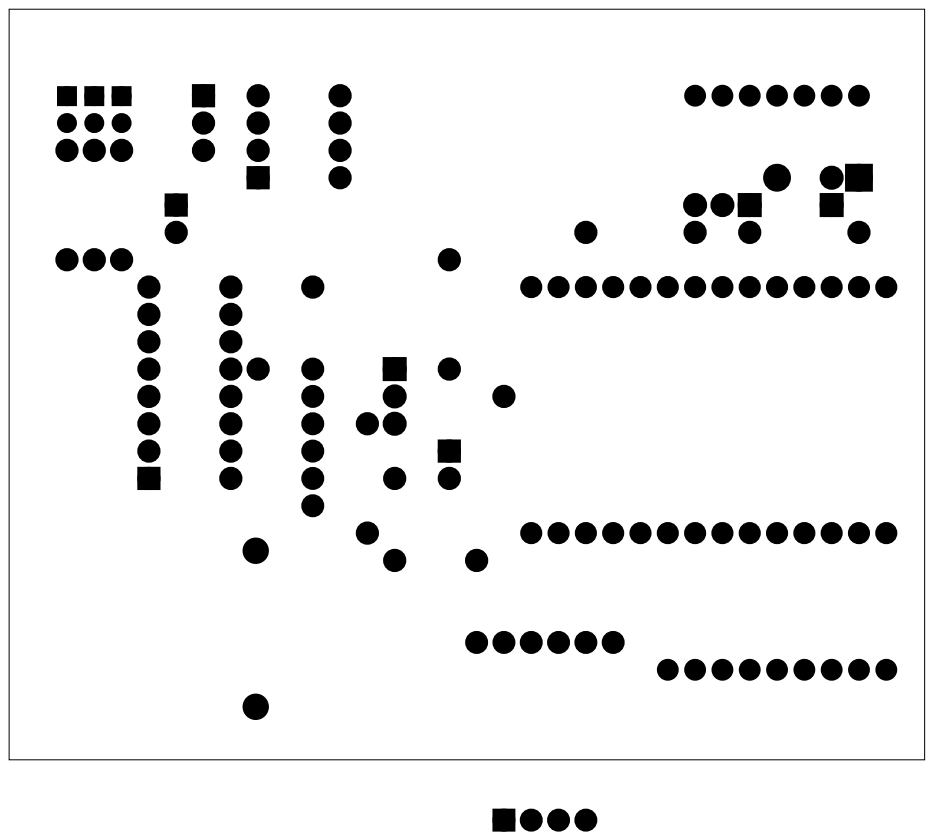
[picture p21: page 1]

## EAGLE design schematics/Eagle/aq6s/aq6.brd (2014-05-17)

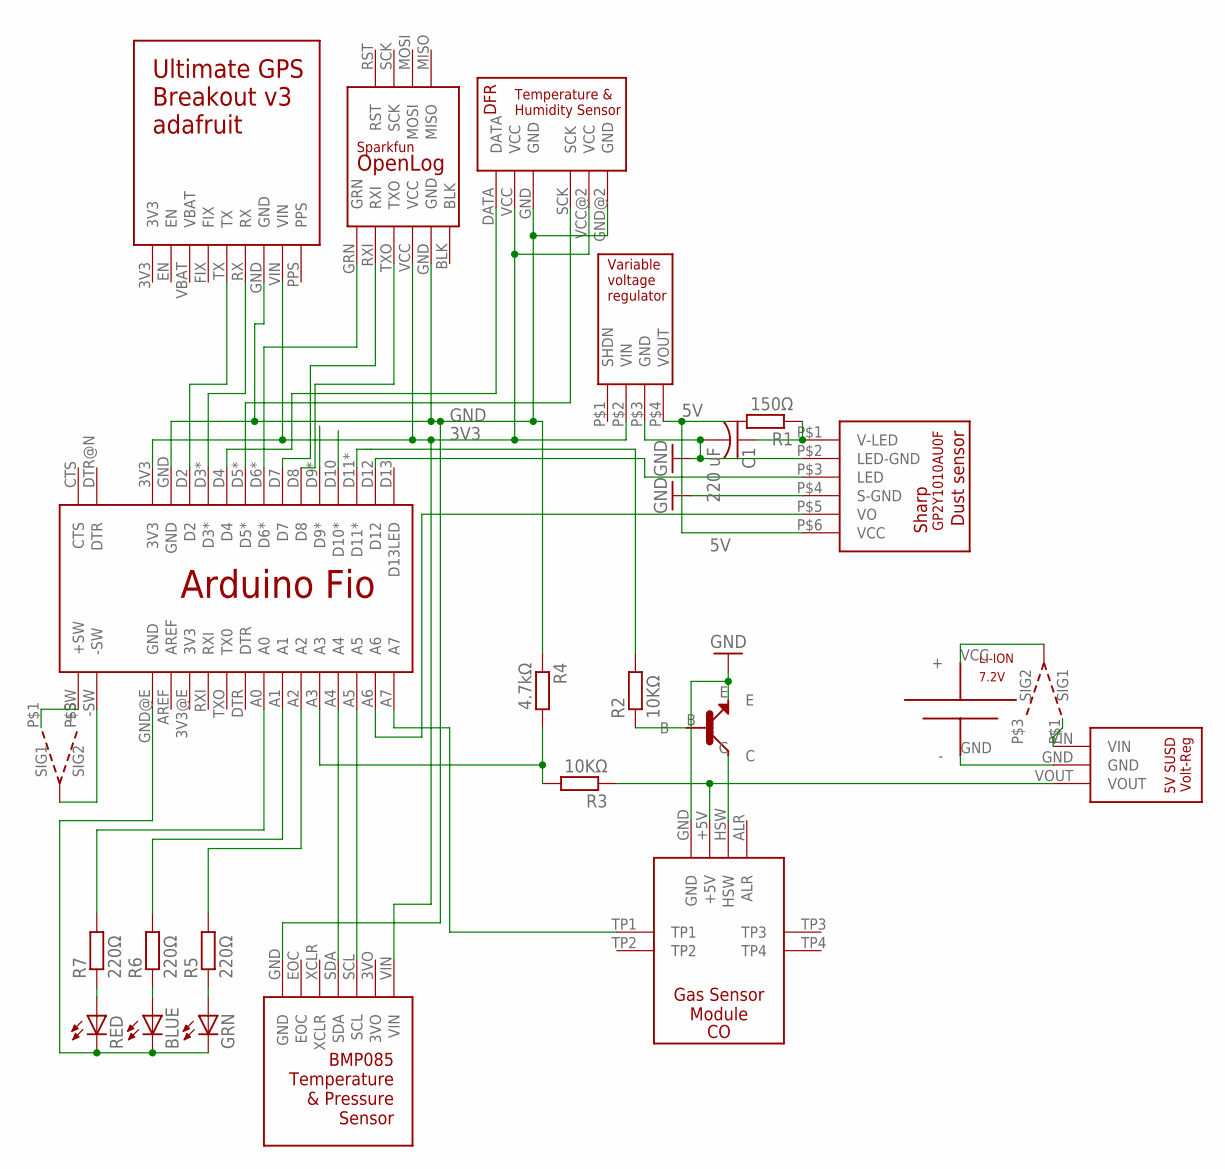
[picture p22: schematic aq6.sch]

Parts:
BLUE: LED5MM
C1: 220 uF; C050-025X075
CO: CO; GSM_PARALLAX
GRN: LED5MM
LI-ION: 7.2V; BATTERY_WITH_WIRE_HOLES
R1: 150Ω; 0207/15
R2, R3: 10KΩ; 0204/7
R4: 4.7kΩ; 0204/7
R5, R6, R7: 220Ω; 0204/7
RED: LED5MM
U$1: SHARP_DUST_SENSOR6PIN; 6PIN
U$2: ARDUINO_FIO
U$3: POLOLU_VAR_VOLTAGE_REG
U$4: ADAFRUIT_GPS_V3
U$5: SPARKFUN_OPENLOG
U$6: DFR_TEMP_HUMIDITY
U$7: 5V_SUSD_VOLT_REG
U$8: BMP085
U$10, U$11: SWITCH
U$12: NPN

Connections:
3V3: U$2.3V3, U$3.P$2 (VIN), U$4.VIN, U$5.VCC, U$6.VCC, U$6.VCC@2 (VCC), U$8.VIN
3VO: U$8.3VO
5V: R1.2, U$1.P$6 (VCC), U$3.P$4 (VOUT)
GND: BLUE.K (C), C1.2, CO.GND, GRN.K (C), LI-ION.GND (-), R4.1, RED.K (C), U$1.P$2 (LED-GND), U$1.P$4 (S-GND), U$2.GND, U$2.GND@E (GND), U$3.P$3 (GND), U$4.GND, U$5.GND, U$6.GND, U$6.GND@2 (GND), U$7.GND, U$8.GND, U$12.E
unnamed: U$1.P$3 (LED), U$2.D12
unnamed: C1.1, R1.1, U$1.P$1 (V-LED)
unnamed: U$1.P$5 (VO), U$2.A6
unnamed: U$2.D3*, U$4.RX
unnamed: U$2.D2, U$4.TX
unnamed: U$2.+SW, U$10.P$1 (SIG1)
unnamed: U$2.D6*, U$5.GRN
unnamed: U$2.D7, U$5.RXI
unnamed: U$2.D8, U$5.TXO
unnamed: U$2.-SW, U$10.P$2 (SIG_OUT)
unnamed: LI-ION.VCC (+), U$11.P$2 (SIG_OUT)
unnamed: U$2.D5*, U$6.SCK
unnamed: U$2.D4, U$6.DATA
unnamed: U$7.VIN, U$11.P$1 (SIG1)
unnamed: R5.2, U$2.A2
unnamed: R2.1, U$12.B
unnamed: R2.2, U$2.D11*
unnamed: CO.+5V, R3.1, U$7.VOUT
unnamed: CO.HSW, U$12.C
unnamed: CO.TP1, U$2.A7
unnamed: R3.2, R4.2, U$2.A3
unnamed: U$2.A4, U$8.SDA
unnamed: U$2.A5, U$8.SCL
unnamed: R7.2, U$2.A0
unnamed: R6.2, U$2.A1
unnamed: R7.1, RED.A
unnamed: BLUE.A, R6.1
unnamed: GRN.A, R5.1

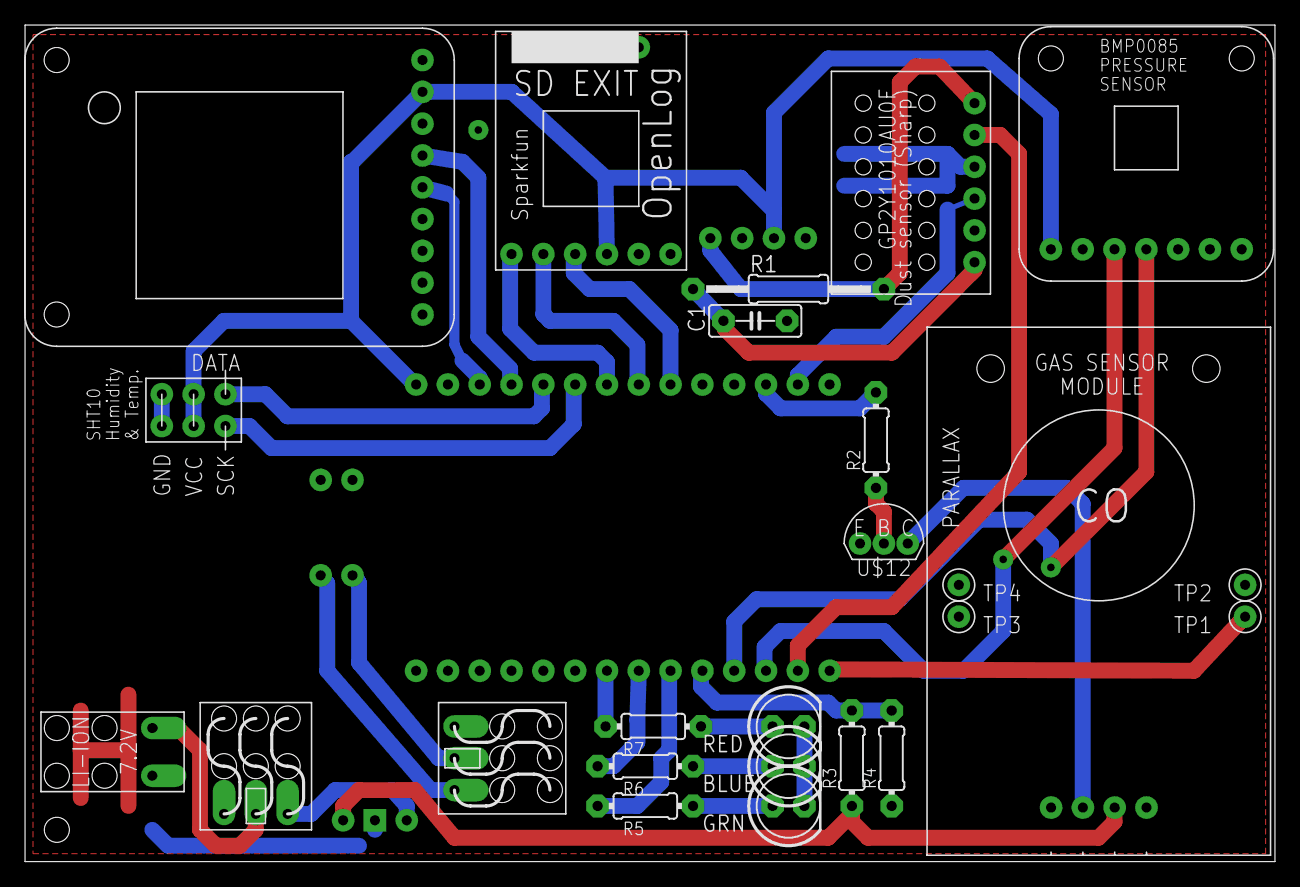
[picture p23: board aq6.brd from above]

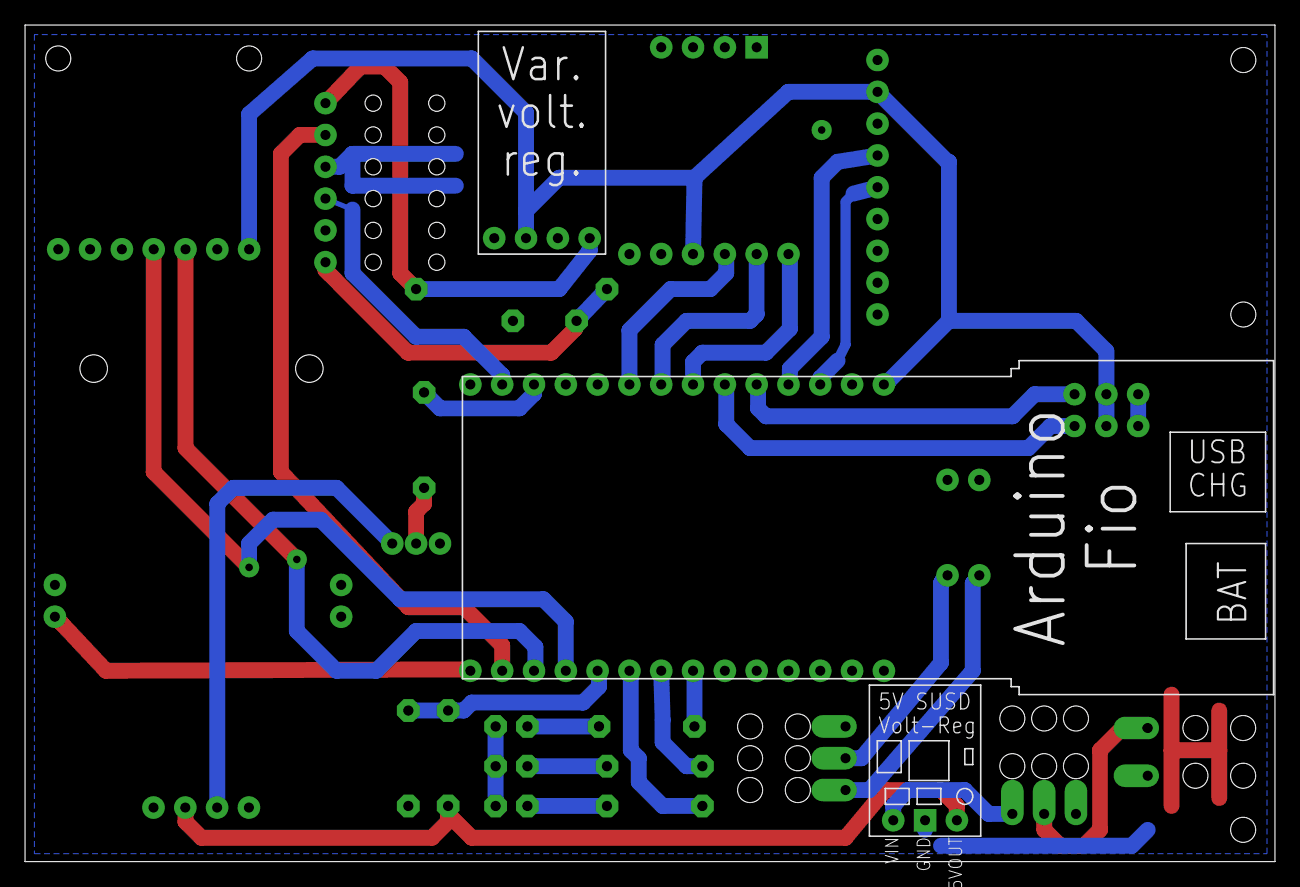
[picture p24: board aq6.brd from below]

Board: 2 copper layers, 99.8 x 66.8 mm, 24 parts (3 on the bottom side), 31 nets.

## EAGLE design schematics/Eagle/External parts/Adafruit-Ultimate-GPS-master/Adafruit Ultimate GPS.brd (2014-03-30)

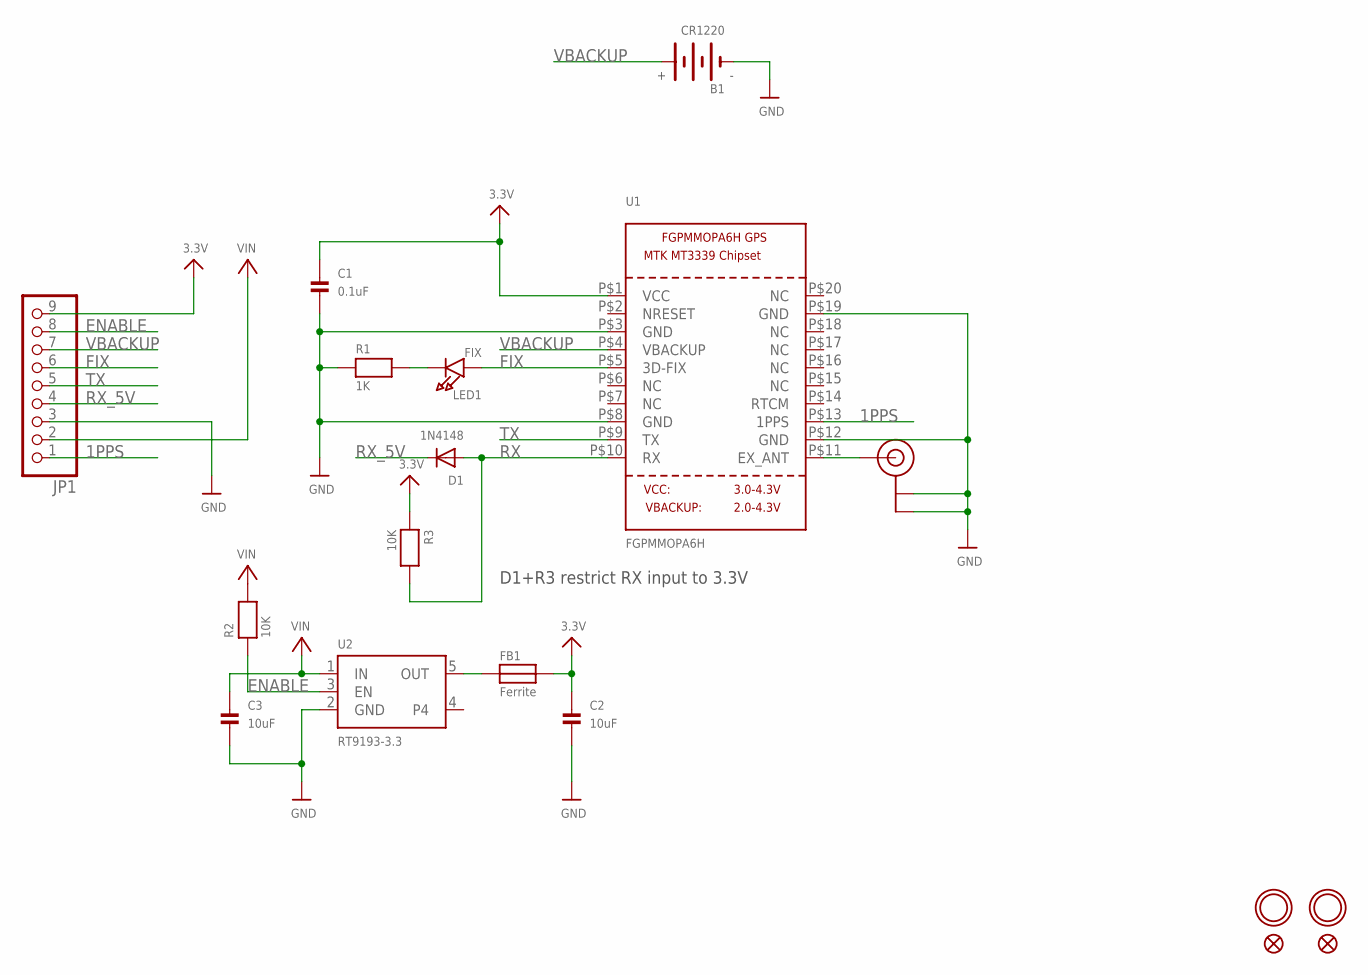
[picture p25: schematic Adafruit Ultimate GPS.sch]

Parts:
B1: CR1220
C1: 0.1uF; 0805
C2, C3: 10uF; 0805
D1: 1N4148; SOD-323F
FB1: Ferrite; 0805
FID1, FID2: FIDUCIAL""; FIDUCIAL_1MM
JP1: HEADER-1X970MIL; 1X09_ROUND_70
LED1: FIX; CHIPLED_0805
R1: 1K; 0805
R2, R3: 10K; 0805
U1: FGPMMOPA6H
U2: RT9193-3.3; SOT23-5
U$8, U$9: MOUNTINGHOLE2.0; MOUNTINGHOLE_2.0_PLATED
U$20: U.FL

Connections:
1PPS: JP1.1, U1.P$13 (1PPS)
3.3V: C1.1, C2.1, FB1.2, JP1.9, R3.1, U1.P$1 (VCC)
ENABLE: JP1.8, R2.1, U2.3 (EN)
FIX: JP1.6, LED1.A, U1.P$5 (3D-FIX)
GND: B1.-, C1.2, C2.2, C3.2, JP1.3, R1.1, U1.P$3 (GND), U1.P$8 (GND), U1.P$12 (GND), U1.P$19 (GND), U2.2 (GND), U$20.P$1 (GND), U$20.P$2 (GND)
unnamed: LED1.C, R1.2
unnamed: FB1.1, U2.5 (OUT)
unnamed: U1.P$11 (EX_ANT), U$20.P$3 (SIGNAL)
RX: D1.A, R3.2, U1.P$10 (RX)
RX_5V: D1.C, JP1.4
TX: JP1.5, U1.P$9 (TX)
VBACKUP: B1.+$1 (+), JP1.7, U1.P$4 (VBACKUP)
VIN: C3.1, JP1.2, R2.2, U2.1 (IN)

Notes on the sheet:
D1+R3 restrict RX input to 3.3V

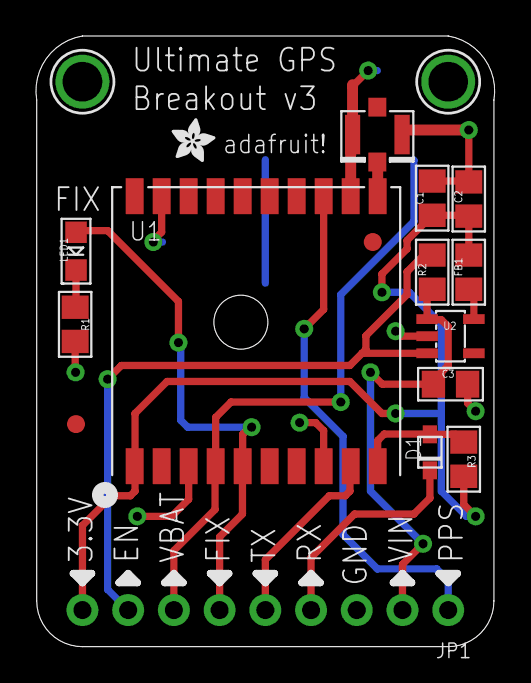
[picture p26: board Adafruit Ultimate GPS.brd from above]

Board: 2 copper layers, 25.5 x 33.9 mm, 19 parts (1 on the bottom side), 13 nets.

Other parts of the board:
U$15: ADAFRUIT_2.5MM

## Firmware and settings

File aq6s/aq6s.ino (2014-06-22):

/*
 Module using an Arduino Fio, a Sharp Optical Dust Sensor GP2Y1010AU0F,
 an Adafruit Ultimate GPS Breakout 3v3 and an OpenLog data logger.
 
 Blog: TO COME
 Code: https://github.com/Trefex/arduino-airquality/

 For Pin connections, please check the Blog or the github project page
 Authors: Cyrille Médard de Chardon (serialC), Christophe Trefois (Trefex)
 Changelog:
   2014-Jun-22: Removed MUX, simplified LED display, OpenLog GPS conflict resolved?
   2014-Feb-09: Fixed OpenLog problems due to dust sensor
   2013-Dec-11: Added CO code through library addition
   2013-Dec-22: Added CO Sensor
   2013-Dec-16: First version working.


 This work is licensed under the Creative Commons Attribution-NonCommercial-ShareAlike 3.0 Unported License. 
 To view a copy of this license, visit http://creativecommons.org/licenses/by-nc-sa/3.0/ or send a letter 
 to Creative Commons, 444 Castro Street, Suite 900, Mountain View, California, 94041, USA. 
 */
 
#include <SoftwareSerial.h>
#include <Wire.h>
#include <Arduino.h>
#include <math.h>

// Allow for basic C++ functions
/*#include <StandardCplusplus.h>
#include <system_configuration.h>
#include <unwind-cxx.h>
#include <utility.h>
#include <vector>

using namespace std;*/

#define USE_OPENLOG // disable to remove logging
#define USE_GPS // disable to remove GPS
#define GPSECHO false // put to true if you want to see raw GPS data flowing
#define USE_BARO // disable to remove Barometric sensor
#define DEBUG_ON // enable to output debugging information on normal Serial
#define USE_HT // comment to remove Humidity and temperature sensor
#define USE_CO // disable to remove CO sensor
#define USE_DUST // disable to remove DUST sensor
#define LEDS     // use Red, Blue, Green leds for indication

// Check which sensors are being used based on defines above
#ifdef USE_BARO
  //#include "Adafruit_BMP085.h"
  #include "Adafruit_BMP085_U.h"
  #include "Adafruit_Sensor.h"
#endif

#ifdef USE_GPS
  #include "Adafruit_GPS.h"
#endif

#ifdef USE_HT
  #include "SHT1x.h"
#endif

#ifdef USE_CO
  #include "COS_MQ7.h"
#endif

// Pin definitions
#define HT_DATA_PIN 5 //D5 - Humidity/Temp sensor data
#define HT_SCK_PIN 4  //D4 - Humidity/Temp sensor serial clock

#define DUST_RX_PIN A6  //A6 - Dust sensor (Analog 6)
#define DUST_LED_PIN 12 //D12 - Dust sensor led

#define OPENLOG_RST_PIN 6 //D6 - Openlogger
#define OPENLOG_RX_PIN 7  //D7 - Openlogger
#define OPENLOG_TX_PIN 8  //D8 - Openlogger

#define ADAGPS_RX_PIN 3 // D3 - GPS RX to Pin ADAGPS_RX_PIN
#define ADAGPS_TX_PIN 2 // D2 - GPS TX to ADAGPS_TX_PIN

#define ACTIVE_MONOX_LED_PIN 10 // CO LED Pin (No led in place in D10 currently)
#define ACTIVE_MONOX_PIN 11 // D5 - CO Switch Pin
#define READ_MONOX_PIN A7 // CO Read Pin
#define READ_COPSV_PIN A3 // CO Power Supply Voltage

#define RED_LED A0
#define BLU_LED A1
#define GRN_LED A2

#ifdef USE_CO
  COS_MQ7 MQ7(ACTIVE_MONOX_LED_PIN, ACTIVE_MONOX_PIN, READ_MONOX_PIN, READ_COPSV_PIN, -1);
#endif

// Constructor declarations
#ifdef USE_HT
  SHT1x th_sensor(HT_DATA_PIN, HT_SCK_PIN);
#endif

#ifdef USE_OPENLOG
  SoftwareSerial OpenLog(OPENLOG_TX_PIN, OPENLOG_RX_PIN);  // TX, RX
#endif

#ifdef USE_BARO
  Adafruit_BMP085_Unified BMP = Adafruit_BMP085_Unified(10050);
#endif

#ifdef USE_GPS
  // Create Soft Serial GPS handle
  SoftwareSerial GPSSerial(ADAGPS_TX_PIN, ADAGPS_RX_PIN);
  // Create GPS handle using GPS Soft Serial
  Adafruit_GPS GPS(&GPSSerial);
#endif

// variable initializations
#ifdef USE_OPENLOG
  //static const int resetOpenLog = OPENLOG_RST_PIN;
  boolean openlog_ready = false;
#endif

// this keeps track of whether we're using the interrupt
// off by default!
boolean usingInterrupt = false;
boolean gpsReady = false;

int samplingTime = 280;
int deltaTime = 40;
int sleepTime = 9680;

float voMeasured = 0;
float calcVoltage = 0;
float dustDensity = 0;
float temp_c = -99;
float humid = -99;

int mainLiPo_mV = -99;

int co_state = -99;
int co_voltage = -99;
int co_reading = -99;

boolean led_pulse = false;

float bmp_temp = 0;
float bmp_pres = 0;

uint32_t timer = millis();

void setup(){
  #ifdef DEBUG_ON
    // 115200 baud rate for connection
    Serial.begin(115200);
  #endif

  // if the initialization of the OpenLog is after the DustSensor output is set to high this doesn't work???!!
  #ifdef USE_OPENLOG
    // Setup and reset OpenLog
    pinMode(OPENLOG_RST_PIN, OUTPUT);
    OpenLog.begin(9600);

    // Reset OpenLog
    digitalWrite(OPENLOG_RST_PIN, LOW);
    delay(100);
    digitalWrite(OPENLOG_RST_PIN, HIGH);
    
    //Wait for OpenLog to respond with '<' to indicate it is alive and recording to a file
    
    while(1) {
      if(OpenLog.available()) {

        // print how much is available
        Serial.print("There are ");Serial.print(OpenLog.available()); Serial.println(" characters available:");
        
        char olr = 'x';
        while( OpenLog.available() > 0) {
          olr = OpenLog.read();
          Serial.print(olr);
          
          if( olr == '<' ) openlog_ready = true;
        }
        Serial.print("\n");
        if( openlog_ready ) break;
        
        delay(2000);
      }
    }
    Serial.println("OpenLog is alive and recording.");
  #endif

  // define dust pins as output mode  
  #ifdef USE_DUST
    pinMode(DUST_LED_PIN, OUTPUT);
  #endif
  
  // define dust pins as output mode, reset GPS and begin GPS device
  #ifdef USE_GPS
    //pinMode(ADAGPS_RESET, OUTPUT);
  
    // reset the GPS (is not connected)
    //digitalWrite(ADAGPS_RESET, LOW);
    //delay(2000);
    //digitalWrite(ADAGPS_RESET, HIGH);
  
    GPS.begin(9600);
    delay(40);
    GPS.sendCommand(PMTK_SET_NMEA_OUTPUT_RMCGGA);
    GPS.sendCommand(PMTK_SET_NMEA_UPDATE_1HZ);   // 1 Hz update rate
  #endif
  
  #ifdef USE_BARO
    BMP.begin();
  #endif
  
  #ifdef LEDS
    pinMode(RED_LED, OUTPUT);
    pinMode(BLU_LED, OUTPUT);
    pinMode(GRN_LED, OUTPUT);
  #endif

  delay(1000);
  #ifdef USE_GPS
    // Ask for firmware version
    GPSSerial.println(PMTK_Q_RELEASE);
  #endif
}

// converts lat/long from Adafruit
// degree-minute format to decimal-degrees
double convertDegMinToDecDeg (float degMin) {
  double minutes = 0.0;
  double decDeg = 0.0;
 
  //get the minutes, fmod() requires double
  minutes = fmod((double)degMin, 100.0);
 
  //rebuild coordinates in decimal degrees
  degMin = (int) ( degMin / 100 );
  decDeg = degMin + ( minutes / 60 );
 
  return decDeg;
}

void loop(){
  delay(2000);
  #ifdef DEBUG_ON
    Serial.println("\nBegining of loop");
  #endif
  
  mainLiPo_mV = readVcc();

  // Take measurement every two seconds
  // if (millis() - timer > 2000) { 
    #ifdef USE_OPENLOG
      // listen for data
      OpenLog.listen();
      delay(20);
    #endif
 
    #ifdef USE_DUST
      digitalWrite(DUST_LED_PIN,LOW); // power on the LED
      delayMicroseconds(samplingTime);
    
      voMeasured = analogRead(DUST_RX_PIN); // read the dust value
      
      delayMicroseconds(deltaTime);
      digitalWrite(DUST_LED_PIN,HIGH); // turn the LED off
      delayMicroseconds(sleepTime);
    
      // VoMeasured returns a value between 0-1023 relative to 3.3V 
      // We convert this value to a voltage value used for dust density
      calcVoltage = 3.3 * (voMeasured / 1023);
      // Note that we use a step up voltage regulator to get 5V powering the dust sensor
      
      // Convert voltage to density
      // Convert voltage to dust density (ug/m3) based on
      // linear eqaution taken from http://www.howmuchsnow.com/arduino/airquality/
      // Chris Nafis (c) 2012
      dustDensity = (0.17 * calcVoltage - 0.1)*1000;
    #endif

    // Get temperature
    #ifdef USE_HT
      // Read values from the sensor, humidity first
      humid = th_sensor.readHumidity();
      temp_c = th_sensor.retrieveTemperatureC();
    #endif
    
    // Cycle Power of CO Sensor
    #ifdef USE_CO
      MQ7.Power_cycle();
      co_state = MQ7.Get_state();
      co_voltage = MQ7.Get_Voltage_reading();
      co_reading = MQ7.Get_current_CO_reading();
      
      // this unblocks CO sensor from waiting for us to retrieve good measure value
      if(MQ7.Get_state() == 4) {
       co_reading = MQ7.Get_CO_reading();
      }
    #endif
    
    #ifdef USE_BARO
      BMP.getTemperature(&bmp_temp);
      BMP.getPressure(&bmp_pres);
      bmp_pres = bmp_pres / 100.0;
    #endif
    
    #ifdef USE_OPENLOG
      OpenLog.print("<< ");
      #ifdef USE_GPS // If using GPS log data if a fix, otherwise write blanks
        if(GPS.fix) {
          // print date time (YYYY-MM-DD HH:MM:SS.00000)
          OpenLog.print("20"); OpenLog.print(GPS.year, DEC); OpenLog.print("-");
          OpenLog.print(GPS.month, DEC); OpenLog.print("-");
          OpenLog.print(GPS.day, DEC); OpenLog.print(" ");
          OpenLog.print(GPS.hour, DEC); OpenLog.print(":");
          delay(15);
          OpenLog.print(GPS.minute, DEC); OpenLog.print(":");
          OpenLog.print(GPS.seconds, DEC); OpenLog.print(GPS.milliseconds); OpenLog.print(",");
          
          // print location (XX.XXXXXN, XX.XXXXXE)
          OpenLog.print(convertDegMinToDecDeg(GPS.latitude)); OpenLog.print(GPS.lat); OpenLog.print(",");
          OpenLog.print(convertDegMinToDecDeg(GPS.longitude)); OpenLog.print(GPS.lon); OpenLog.print(",");
          
          // Fix quality, speed, angle/direction of travel, altitude, satellites locked
          OpenLog.print((int)GPS.fixquality); OpenLog.print(",");
          OpenLog.print(GPS.speed); OpenLog.print(",");
          OpenLog.print(GPS.angle); OpenLog.print(",");
          OpenLog.print((int)GPS.satellites); OpenLog.print(",");
          
        } else {
          OpenLog.print(",,,,,,,");
        }
      #endif

      #ifdef USE_DUST
        // Dust Values
        OpenLog.print(dustDensity); OpenLog.print(",");
        delay(15);
      #endif
      
      #ifdef USE_BARO
         OpenLog.print(bmp_temp); OpenLog.print(",");
         OpenLog.print(bmp_pres); OpenLog.print(",");
         delay(15);
      #endif
      
      #ifdef USE_HT
        OpenLog.print(temp_c); OpenLog.print(",");
        OpenLog.print(humid); OpenLog.print(",");
      #endif
      
      #ifdef USE_CO
        OpenLog.print(co_state); OpenLog.print(",");
        OpenLog.print(co_voltage); OpenLog.print(",");
        OpenLog.print(co_reading); OpenLog.print(",");
      #endif
      
      OpenLog.print(mainLiPo_mV);
      
      OpenLog.print("\n");          
      delay(15);
    #endif

    // Debug/test printout of sensor values    
    #ifdef DEBUG_ON
      #ifdef USE_BARO
        Serial.print("\nTemperature: "); Serial.print(bmp_temp); Serial.println(" [*C]");
        Serial.print("Pressure: "); Serial.print(bmp_pres); Serial.println(" [hPa]");
      #endif
      
      #ifdef USE_DUST
        Serial.print("Dust Density: ");  Serial.print(dustDensity); Serial.println(" [ug/m3]");
        Serial.print("Voltage Calculated: ");  Serial.print(calcVoltage); Serial.println(" [V]");
        Serial.print("Analogue Read: ");  Serial.print(voMeasured); Serial.println(" [0-1023]");
      #endif
      
      #ifdef USE_HT
        Serial.print("Temperature: "); Serial.print(temp_c); Serial.println(" [*C]");
        Serial.print("Humidity: "); Serial.print(humid); Serial.println(" [%] RH");
      #endif
      
      #ifdef USE_CO
        Serial.print("\n");
        Serial.print("CO Sensor State: "); Serial.println(co_state);
        Serial.print("CO Voltage Reading: "); Serial.println(co_voltage);
        Serial.print("CO Current Reading: "); Serial.println(co_reading);
      #endif
      // check arduino LiPo battery level
      Serial.print("Main LiPo voltage: "); Serial.println(mainLiPo_mV);
    #endif
 // }
  
  #ifdef USE_GPS
    GPSSerial.listen();
    //delay(1000);
  #endif

  #ifdef USE_GPS
    unsigned long start = millis(); // begin listening to the GPS
    // Listen to GPS for two seconds or until fix has been reached, whichever comes first
    while (start + 2000 > millis()) {
      if (! usingInterrupt) {
          // read data from the GPS in the 'main loop'
          char c = GPS.read();
          // if you want to debug, this is a good time to do it!
          if (GPSECHO)
            if (c) UDR0 = c;
            // writing direct to UDR0 is much much faster than Serial.print 
            // but only one character can be written at a time. 
      }
      
 
      // if a sentence is received, we can check the checksum, parse it...
      //Serial.println("Before newNMEA");
      if (GPS.newNMEAreceived()) {
        // a tricky thing here is if we print the NMEA sentence, or data
        // we end up not listening and catching other sentences! 
        // so be very wary if using OUTPUT_ALLDATA and trytng to print out data
        //Serial.println(GPS.lastNMEA());   // this also sets the newNMEAreceived() flag to false
        //Serial.println("New GPS Sentence received");
        //gpsReady = true;
        //break;
        //Serial.println("Before GPS.lastNMEA");
        char * raw_gps;
        raw_gps = GPS.lastNMEA();
        if (GPS.parse(raw_gps)){   // this also sets the newNMEAreceived() flag to false
        //Serial.println("Before GPS fix");
          if (GPS.fix) {
            #ifdef DEBUG_ON
                Serial.print("\nTime: ");
                Serial.print(GPS.hour, DEC); Serial.print(':');
                Serial.print(GPS.minute, DEC); Serial.print(':');
                Serial.print(GPS.seconds, DEC); Serial.print('.');
                Serial.println(GPS.milliseconds);
                Serial.print("Date: ");
                Serial.print(GPS.day); Serial.print('/');
                Serial.print(GPS.month, DEC); Serial.print("/20");
                Serial.println(GPS.year, DEC);
                Serial.print("Fix: "); Serial.print((int)GPS.fix);
                Serial.print(" quality: "); Serial.println((int)GPS.fixquality); 
                Serial.print("Lat, Lng: ");
                Serial.print(convertDegMinToDecDeg(GPS.latitude),6); Serial.print(GPS.lat);
                Serial.print(", "); 
                Serial.print(convertDegMinToDecDeg(GPS.longitude),6); Serial.println(GPS.lon);
                
                Serial.print("Speed (knots): "); Serial.println(GPS.speed);
                Serial.print("Angle: "); Serial.println(GPS.angle);
                Serial.print("Altitude: "); Serial.println(GPS.altitude);
                Serial.print("Satellites: "); Serial.println((int)GPS.satellites);
                break;
            #endif
          } else {
            #ifdef DEBUG_ON
              Serial.println("No GPS fix achieved:");
            #endif
          }
          Serial.println(raw_gps);
        }
      }
    }
  #endif
  
  #ifdef LEDS
    // all leds off
    digitalWrite(RED_LED, LOW);
    digitalWrite(BLU_LED, LOW);
    digitalWrite(GRN_LED, LOW);
  
    // display led status
    // we have two pulse stages to alternate leds and reduce current draw
    if ( led_pulse ) {
      led_pulse = false;
      
      #ifdef USE_GPS
        // see if we have GPS fix
        if ( GPS.fix ) {
          // turn on blue led
          digitalWrite(BLU_LED, HIGH);
        }
      #endif
      
      // Green LED stays on when voltage is high, blinks if low voltage - needs calibrating
      if ( mainLiPo_mV > 3000 ) {
        digitalWrite(GRN_LED, HIGH);
      }
    } else {
      // fio is on so turn on the green led
      digitalWrite(GRN_LED, HIGH);
      led_pulse = true;
      
      // see if the CO battery voltage is low (under 5 volts)
      if ( co_voltage < 500 ) {
        // turn on red led
        digitalWrite(RED_LED, HIGH);
      }      
    }
  #endif
  
  
  // if millis() or timer wraps around, we'll just reset it
  if (timer > millis())  timer = millis();
  //clearSerial();
  //delay(400);
}

// Function retrieves voltage of Fio
// Code source: Scott Daniels http://provideyourown.com/2012/secret-arduino-voltmeter-measure-battery-voltage/
long readVcc() {
  // Read 1.1V reference against AVcc
  // set the reference to Vcc and the measurement to the internal 1.1V reference
  #if defined(__AVR_ATmega32U4__) || defined(__AVR_ATmega1280__) || defined(__AVR_ATmega2560__)
    ADMUX = _BV(REFS0) | _BV(MUX4) | _BV(MUX3) | _BV(MUX2) | _BV(MUX1);
  #elif defined (__AVR_ATtiny24__) || defined(__AVR_ATtiny44__) || defined(__AVR_ATtiny84__)
    ADMUX = _BV(MUX5) | _BV(MUX0);
  #elif defined (__AVR_ATtiny25__) || defined(__AVR_ATtiny45__) || defined(__AVR_ATtiny85__)
    ADMUX = _BV(MUX3) | _BV(MUX2);
  #else
    ADMUX = _BV(REFS0) | _BV(MUX3) | _BV(MUX2) | _BV(MUX1);
  #endif  
 
  delay(2); // Wait for Vref to settle
  ADCSRA |= _BV(ADSC); // Start conversion
  while (bit_is_set(ADCSRA,ADSC)); // measuring
 
  uint8_t low  = ADCL; // must read ADCL first - it then locks ADCH  
  uint8_t high = ADCH; // unlocks both
 
  long result = (high<<8) | low;
 
  result = 1125300L / result; // Calculate Vcc (in mV); 1125300 = 1.1*1023*1000
  return result; // Vcc in millivolts
}

//void clearSerial() {
//  #ifdef DEBUG_ON
//    while (Serial.read() >= 0) {;}
//  #endif
//  #ifdef USE_GPS
//    while(GPSSerial.read() >= 0) {;}
//  #endif
//  //while(OpenLog.read() >= 0){;}
//}

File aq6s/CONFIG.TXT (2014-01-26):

9600,26,3,0,1,1

baud,escape,esc#,mode,verb,echo

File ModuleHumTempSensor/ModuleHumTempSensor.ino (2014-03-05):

/**
 * Humidity - Temperature sensor module
 * Cyrille Medard de Chardon, Christophe Trefois
 */

#include "SHT1x.h"
#define dataPin 7
#define sckPin 8 //serial clock

// We are using the SHT10
// Humid accuracy +/- 5%
// Steady accuracy between 10-80
// example at 10/90 +/- 6%, 0/100 +/- 7.5%

// Temp accuracy +/- .5 degrees celsius
// Temp error increases more as we get farther from 25 cels.
// example: @ 0/50 degrees, +/- 1.2 degrees

SHT1x th_sensor(dataPin, sckPin);

void setup()
{
  Serial.begin(9600);
  Serial.println("Starting up");
}

void loop()
{  
  float temp_c;
  float humid;
  
  // Read values from the sensor
  humid = th_sensor.readHumidity();
  // Since the humidity reading requires the temperature we simply
  // retrieve the reading capture from the readHumidity() call. See the lib.
  temp_c = th_sensor.retrieveTemperatureC();
  
  // Print data
  Serial.print("Temperature: ");
  Serial.print(temp_c);
  Serial.print(", Humidity: ");
  Serial.println(humid);

  delay(4000);
}

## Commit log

2012-12-01 - Initial Import of CO Sensor Module Project and Documentation
2012-12-01 Fixed sensor type
2012-12-01 Added Assembly sketch for Dust Sensor w/ Arduino Fio
    [Arduino_Fio_Sketch_Fritzing.fzz]
2012-12-01 Changed folder name to assembly
    [Arduino_Fio_Sketch_Fritzing.fzz]
2012-12-01 Updated Module_Dust-Sensor/README.md
2012-12-01 Example output was taken with 5V Arduino Uno
2012-12-13 - Converted mg/m3 to ug/m3 which seems to be the accepted standard - Added images from the Blog - Added output for airquality sensor with the Fio
2012-12-16 - Initial commit of Dust Sensor + OpenLog + Adafruit GPS
2012-12-17 - Cleaned up code - Added Barometric Sensor but not used in this code
    [ArduinoFio_OpenLog_GPS_Sharp.fzz]
2013-03-16 - Addition of Barometer sensor
2013-03-16 Created the new folder holding the 5 sensors and libraries all together Code compiles successfully!
2013-03-16 Updated the humidity-temp module to work out of the box: - updated file names - moved them around - updated readme/changes - set #include path to relative - no longer need to move anything to the lib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
    [ModuleHumTempSensor.ino, SHT1x.cpp]
2013-10-16 Have the 5 sensors working together correctly"
    [aq5s.ino, dustSensor.ino]
2013-11-27 first attempt - not working, wiring has logic problems?
2013-11-30 Works after joining both power supply grounds
2013-12-01 Added idea for additional sensors
2013-12-21 Finished CO code with PWM
2013-12-22 - Initial Import of CO Sensor Module Added - Untested code
2013-12-22 - Fixed small bug around CO code
    [aq6s.ino]
2013-12-23 Uses pin 13 to indicate if heating the coil
2013-12-23 added voltage monitoring to circuit
2014-01-04 Updated CitizSensor library, bugs in sketch
    [CS_MQ7.cpp]
2014-01-10 fixed cycle state bug
    [COS_MQ7.cpp, CO_Sensor.ino]
2014-01-11 Fixed pin for CO
    [aq6s.ino]
2014-01-26 CO working, Logger not working - GPS conv. prob?
    [COS_MQ7.cpp, aq6s.ino]
2014-01-26 Added some doc, config, outputs
    [CONFIG.TXT]
2014-01-29 Minor changes to GPS printouts and OpenLog messages
2014-02-09 Fixed OpenLog problems due to dust sensor, cleaned Breadboard
    [OpenLogSerialTest.ino, aq6s.ino]
2014-02-18 Updated CO_sensor, added mux status leds
2014-02-19 Update README.md
    Added Barometric sensor reference
2014-02-24 Created PCB schematic in fritzing , needs custom components.
    [aq6s.fzz]
2014-03-21 Updated PCB, need to update pins in code!
    [aq6s.fzz]
2014-03-24 Created first PCB draft design, pins have changed! Update code!
    [aq6s.fzz]
2014-03-27 Finished fritzing PCB, don't like it. Started Eagle cad PCB.
    [aq6.brd, aq6.sch, aq6s.fzz]
2014-03-30 Added more components to Eagle schematic, library
    [Adafruit Ultimate GPS.brd, Adafruit Ultimate GPS.sch, aq6.brd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]
2014-03-31 Finished circuit diagram, needs checking
    [aq6.brd, aq6.sch]
2014-04-05 PCB layout tentatively ok, routing next
    [aq6.brd, aq6.sch]
2014-04-09 PCB first draft, needs checking and adjustment
    [aq6.brd, aq6.sch]
2014-05-02 Removed mux/bit shift register
    [aq6.brd, aq6.sch]
2014-05-03 Thickened pcd traces
    [aq6.brd, aq6.sch]
2014-05-05 pcb images
    [aq6.brd]
2014-05-05 pcb first etch design
2014-05-15 Fixed pcb, reexport to png! Update Ard. code
    [aq6.brd, aq6.sch]
2014-05-15 Updated pcb images: bottom, top
    [aq6.brd]
2014-05-17 pcb and code updates
    [aq6.brd]
2014-05-28 Updated arduino code
2014-05-30 Changed pins, fixed CO reporting - Logger not working
    [battery_holder.skp, battery_holder.stl, battery_holder~.skp]
2014-06-14 Edited battery holder, flexibility and length
    [battery_holder.skp, battery_holder~.skp]
2014-06-14 Added 3d model files - need to print gcode
    [battery_holder_stretch.skp, battery_holder_stretch~.skp]
2014-06-22 Edited battery, code - v1?
    [battery_holder_stretch.skp, battery_holder_stretch~.skp]
